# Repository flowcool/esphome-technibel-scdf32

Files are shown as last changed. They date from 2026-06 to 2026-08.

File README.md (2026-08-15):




[]()

**[🇬🇧 English](#-english)** · **[🇫🇷 Français](#-français)**

---

# ESPHome — Technibel SCDF32C5I IR Climate

> Fully reverse-engineered IR protocol + complete ESPHome / Home Assistant integration.  
> Protocole IR entièrement décodé + intégration ESPHome / Home Assistant complète.

---

## 🇬🇧 English

### What this is

This repository provides everything needed to control a **Technibel SCDF32C5I**
split air conditioner from Home Assistant using an ESP32 as an IR blaster.

The IR protocol was fully reverse-engineered from raw captures — Technibel uses a
**proprietary 48-bit protocol** that is not recognized by IRremoteESP8266. The frame
structure, encoding, and checksum formula are documented in [`docs/protocol.md`](docs/protocol.md).

**What you get:**
- `technibel_ir.h` — C++ IR frame builder (48-bit, checksum included)
- `ir-technibel-clim.yaml` — ESPHome transmitter config exposing a `send_command` service
- `ir-clim-sniffer.yaml` — ESPHome receiver config for capturing raw IR frames (debug use)
- `climate-technibel-ha.yaml` — Home Assistant MQTT climate entity (full package)

### Hardware (BOM)

See [`docs/bom.md`](docs/bom.md) for the full bill of materials.

| Component | Reference | Notes |
|---|---|---|
| MCU | ESP32 DevKit 30-pin | Any ESP32 board works |
| IR emitter | Diymore PCB0100 (2-channel) | Transistor + resistors built-in |
| IR receiver | KY-022 / VS1838B 38kHz | Sniffer phase only, not needed in final build |
| Capacitor | 100µF 16V electrolytic | Power filtering near TX module |

### Wiring

See [`docs/wiring.md`](docs/wiring.md) for the full ASCII diagram.

```
ESP32 GPIO4  ──► Diymore PCB0100 IN1   (IR transmitter)
ESP32 GPIO23 ◄── KY-022 OUT            (IR receiver — sniffer only)
```

### Installation

1. Copy `esphome/libraries/technibel_ir.h` to your ESPHome `config/libraries/` directory.
2. Flash `esphome/ir-technibel-clim.yaml` to your ESP32.
3. Add your `wifi_ssid`, `wifi_password`, and `ota_password` to your `secrets.yaml`.
4. In Home Assistant, add `homeassistant/climate-technibel-ha.yaml` to your packages directory.
5. Restart Home Assistant. The `climate.clim_sejour` entity will appear.

> **Note:** Adjust `sensor.thermometre_espace_de_vie_temperature` in `climate-technibel-ha.yaml`
> to match your own ambient temperature sensor entity ID.

### Usage in Home Assistant

Once installed, `climate.clim_sejour` supports:

| Feature | Values |
|---|---|
| HVAC modes | `off`, `cool`, `dry`, `fan_only`, `auto` |
| Fan modes | `auto`, `1`, `2`, `3`, `4`, `5`, `6` |
| Temperature range | 16°C – 30°C (1°C step) |
| Current temperature | From your HA temperature sensor |

Every state change (mode, temperature, fan speed) automatically sends the full IR
command to the AC via the ESP32.

### Protocol regression check

Run the dependency-free protocol verifier after changing captures, documentation,
or frame-generation code. It does not compile ESPHome or contact live devices:

```bash
python3 tests/verify_protocol.py
```

### Protocol overview

The Technibel SCDF32C5I uses a proprietary 48-bit IR protocol at 38kHz.
Frame: `B0 B1 B2 B3 B4 B5` (6 bytes). Checksum includes ambient temperature.

→ Full details in [`docs/protocol.md`](docs/protocol.md)

---

## 🇫🇷 Français

### Description

Ce dépôt contient tout le nécessaire pour piloter un climatiseur **Technibel SCDF32C5I**
depuis Home Assistant via un ESP32 émetteur IR.

Le protocole IR a été entièrement décodé par reverse engineering — Technibel utilise un
**protocole propriétaire 48 bits** non reconnu par IRremoteESP8266. C'est probablement
la première documentation publique de ce protocole.

**Contenu :**
- `technibel_ir.h` — constructeur de trames IR en C++ (48 bits, checksum inclus)
- `ir-technibel-clim.yaml` — config ESPHome émetteur, expose un service `send_command`
- `ir-clim-sniffer.yaml` — config ESPHome récepteur pour capture de trames brutes (debug)
- `climate-technibel-ha.yaml` — entité climate MQTT pour Home Assistant (package complet)

### Matériel (BOM)

Voir [`docs/bom.md`](docs/bom.md) pour la liste complète.

| Composant | Référence | Notes |
|---|---|---|
| MCU | ESP32 DevKit 30 broches | N'importe quel ESP32 fonctionne |
| Émetteur IR | Diymore PCB0100 (2 canaux) | Transistor + résistances intégrés |
| Récepteur IR | KY-022 / VS1838B 38kHz | Phase sniffer uniquement, inutile en prod |
| Condensateur | 100µF 16V électrolytique | Filtrage alim près du module TX |

### Câblage

Voir [`docs/wiring.md`](docs/wiring.md) pour le schéma ASCII complet.

```
ESP32 GPIO4  ──► Diymore PCB0100 IN1   (émetteur IR)
ESP32 GPIO23 ◄── KY-022 OUT            (récepteur IR — sniffer uniquement)
```

### Installation

1. Copier `esphome/libraries/technibel_ir.h` dans le dossier `config/libraries/` de votre ESPHome.
2. Flasher `esphome/ir-technibel-clim.yaml` sur votre ESP32.
3. Ajouter vos `wifi_ssid`, `wifi_password` et `ota_password` dans `secrets.yaml`.
4. Dans Home Assistant, ajouter `homeassistant/climate-technibel-ha.yaml` dans votre dossier `packages/`.
5. Redémarrer Home Assistant. L'entité `climate.clim_sejour` apparaît.

> **Note :** Remplacer `sensor.thermometre_espace_de_vie_temperature` dans `climate-technibel-ha.yaml`
> par l'entity_id de votre propre capteur de température ambiante.

### Utilisation dans Home Assistant

L'entité `climate.clim_sejour` une fois installée supporte :

| Fonction | Valeurs |
|---|---|
| Modes HVAC | `off`, `cool`, `dry`, `fan_only`, `auto` |
| Vitesses ventilateur | `auto`, `1`, `2`, `3`, `4`, `5`, `6` |
| Plage température | 16°C – 30°C (pas 1°C) |
| Température courante | Depuis votre capteur HA |

### Vérification de non-régression du protocole

Après toute modification des captures, de la documentation ou du générateur de
trames, lancer le vérificateur sans dépendance. Il ne compile pas ESPHome et ne
contacte aucun appareil :

```bash
python3 tests/verify_protocol.py
```

### Aperçu du protocole

Le Technibel SCDF32C5I utilise un protocole IR propriétaire 48 bits à 38kHz.
Trame : `B0 B1 B2 B3 B4 B5` (6 octets). Le checksum intègre la température ambiante.

→ Documentation complète dans [`docs/protocol.md`](docs/protocol.md)

---

## Protocol summary / Résumé protocole

| Byte | Value | Description |
|---|---|---|
| B0 | `0xD0` | Device address (fixed / fixe) |
| B1 | ambient+mode | High nibble = ambient temperature, low nibble: COOL=`0xC`, DRY=`0xA`, FAN=`0x9`, AUTO=`0xD` |
| B2 | temp+fan | hi nibble = temp encoded, lo nibble = fan speed |
| B3 | `0x18`/`0x08` | Power ON / OFF |
| B4 | `0x03` | Fixed / Fixe |
| B5 | checksum | Includes ambient temperature / Intègre T° ambiante |

→ [`docs/protocol.md`](docs/protocol.md) for full encoding tables and checksum formula.

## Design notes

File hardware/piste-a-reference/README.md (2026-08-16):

# Piste A reference perfboard

This directory is the construction authority for the fresh Phase 10 reference
board. The previous hand-drawn/SVG layout is obsolete and must not be used.

## Orientation and coordinates

- Board: isolated-pad FR4 perfboard, 30 × 70 mm, 10 columns × 24 rows.
- Component-side coordinates: columns `A`–`J` left to right, rows `1`–`24`
  top to bottom.
- The XIAO USB-C connector faces row 1.
- The solder-side PDF is already mirrored to match the board as held with the
  solder side facing the operator. Do not mirror it again.

## XIAO ESP32-C3 pin mapping

The schematic and PCB both represent the complete 2×7 XIAO socket:

| Left row, top to bottom | Function | Right row, top to bottom | Function |
|---:|---|---:|---|
| 1 | D0 | 8 | 5V / VBUS |
| 2 | D1 / GPIO3 | 9 | GND |
| 3 | D2 | 10 | 3V3 |
| 4 | D3 | 14 | D10 |
| 5 | D4 | 13 | D9 |
| 6 | D5 | 12 | D8 |
| 7 | D6 | 11 | D7 |

Only pins 2, 8, 9, and 10 are electrically used by this board. All other XIAO
pins remain available and unconnected.

## Mandatory polarity and pinout

- `Q1` is the Mouser onsemi `BC33740BU`. With the flat face toward the observer
  and leads down: pin 1 = Collector, pin 2 = Base, pin 3 = Emitter (`C-B-E`).
- `D1` must be a fresh Mouser Vishay `TSAL6400`: pin 2/anode/long lead at `F23`;
  pin 1/cathode/short lead/flat side at `G23`.
- `C3`: positive pin 1 at `J19`; negative pin 2/stripe at `I19`.
- `C2` and `C3` are directly across 5V and GND, before `R3`.

## Construction hold point

Before soldering, review these native and textual artifacts together:

1. `piste-a-reference.kicad_sch`
2. `piste-a-reference.kicad_pcb`
3. `wiring-table.md`

The current partially assembled board remains untouched as rollback/evidence.
Construction uses a new perfboard and fresh driver components.

## Verification

Install KiCad 9+ and run:

```bash
./verify-design.sh
```

The gate passes only when ERC reports zero errors/warnings and DRC reports zero
violations, zero unconnected pads, and zero schematic-parity problems.

The generator additionally requires `kicad-sch-api==0.5.6`:

```bash
python3 -m venv /tmp/piste-a-kicad-venv
/tmp/piste-a-kicad-venv/bin/pip install -r requirements.txt
/tmp/piste-a-kicad-venv/bin/python generate_design.py
```

Regeneration is deterministic for component placement, net assignments, and
wire coordinates. KiCad-generated UUIDs in the schematic may differ after a
full regeneration.

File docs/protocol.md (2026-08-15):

# Technibel SCDF32C5I — IR Protocol Documentation

**[🇬🇧 English](#-english)** · **[🇫🇷 Français](#-français)**

---

## 🇬🇧 English

### Overview

The Technibel SCDF32C5I uses a **proprietary 48-bit IR protocol** at 38kHz carrier frequency.
It is **not recognized** by IRremoteESP8266 (reported as UNKNOWN). Frames are static and
replayable — no rolling code.

| Parameter | Value |
|---|---|
| Carrier frequency | 38kHz |
| Frame length | 48 bits (6 bytes) |
| Header pulse | 6500µs |
| Header space | 3300µs |
| Bit pulse | ~450µs |
| Bit 1 space | ~2200µs |
| Bit 0 space | ~900µs |
| Bit order | MSB first per byte |

### Frame Structure

```
[ HEADER ] [ B0 ] [ B1 ] [ B2 ] [ B3 ] [ B4 ] [ B5 ] [ final pulse ]
```

| Byte | Example | Description |
|---|---|---|
| B0 | `0xD0` | Device address — always fixed |
| B1 | `0xAC` | Ambient temperature high nibble + operating mode nibble |
| B2 | `0x28` | Temperature (hi nibble) + fan speed (lo nibble) |
| B3 | `0x18` | Power ON flag (`0x08` = OFF) |
| B4 | `0x03` | Fixed — always `0x03` |
| B5 | checksum | Computed from B1, B2, and B3 |

### Mode encoding (B1 low nibble)

| Mode | Low nibble |
|---|---|
| COOL | `0xC` |
| DRY | `0xA` |
| FAN only | `0x9` |
| AUTO | `0xD` |

The high nibble of B1 carries the ambient temperature using the same encoding
as B2: `(reverseBits8(T_ambient - 4) >> 4) & 0xF`. For example, ambient 25°C
with COOL gives `B1=0xAC`, ambient 26°C gives `B1=0x6C`, and ambient 27°C
gives `B1=0xEC`.

> OFF is not a mode value — it is encoded in B3 (see Power flag below).

### Temperature encoding (B2 hi nibble)

Formula: `temp_hi = (reverseBits8(consigne - 4) >> 4) & 0xF`

| Temp | B2 hi nibble (hex) | Verified |
|---|---|---|
| 16°C | `0x90` | generated |
| 17°C | `0x10` | generated |
| 18°C | `0x70` | ✅ captured |
| 19°C | `0xF0` | ✅ captured |
| 20°C | `0x08` | ✅ captured |
| 21°C | `0x88` | generated* |
| 22°C | `0x48` | ✅ captured |
| 23°C | `0xC8` | ✅ captured |
| 24°C | `0x28` | ✅ captured |
| 25°C | `0xA8` | ✅ captured |
| 26°C | `0x68` | ✅ captured |
| 27°C | `0xE8` | generated |
| 28°C | `0x18` | generated |
| 29°C | `0x98` | generated |
| 30°C | `0x58` | generated |

*21°C capture was corrupted (AC displayed 24°C at capture time) — value generated from formula.

### Fan speed encoding (B2 lo nibble)

| Remote level | lo nibble | Captured frame (FAN, 23°C, ambient 24°C) |
|---|---|---|
| AUTO | `0x8` | `D0 29 C8 18 03 51` |
| FAN 1 / LOW | `0xC` | `D0 29 CC 18 03 55` |
| FAN 2 | `0xA` | `D0 29 CA 18 03 53` |
| FAN 3 / MED | `0xE` | `D0 29 CE 18 03 57` |
| FAN 4 | `0x9` | `D0 29 C9 18 03 50` |
| FAN 5 | `0xD` | `D0 29 CD 18 03 54` |
| FAN 6 / HIGH | `0xB` | `D0 29 CB 18 03 52` |

All seven values were captured in one controlled campaign on 2026-08-15. The
complete raw timings are preserved in `captures/fan-campaign-2026-08-15.jsonl`.

### B2 full formula

```
B2 = (temp_hi_nibble << 4) | fan_lo_nibble
```

Example: COOL, 24°C, AUTO fan → `B2 = (0x2 << 4) | 0x8 = 0x28`

### Power / change flag (B3)

| Value | Meaning |
|---|---|
| `0x18` | Power ON (or command update while running) |
| `0x08` | Power OFF |

> Always use `0x18` when sending a command from Home Assistant, even just to change
> the setpoint — the AC needs this flag to apply the new value.

### Checksum (B5)

```
B5 = reverseBits8(
       (reverseBits8(B1) + reverseBits8(B2) + reverseBits8(B3) + 0xCB) & 0xFF
     )
```

The ambient temperature is included indirectly through the high nibble of B1,
and the operating mode through its low nibble. The former formula using
`T_ambient - 25` was a COOL-only reduction: for COOL, B1's low nibble is fixed
to `0xC`, so `reverseBits8(B1) + 0xCB` reduces to `T_ambient - 25` modulo 256.
It must not be used for DRY, FAN, or AUTO frames.

### OFF frame (fixed)

```
D0 AC A8 08 03 A4
```

This frame was pre-computed with B3=`0x08` (power off) and ambient=25°C.
It reliably turns off the AC regardless of the previous mode or setpoint.

### Reverse engineering notes

- Captured using ESP32 + KY-022 TSOP IR receiver + ESPHome `remote_receiver` (`dump: all`)
- Decoded from Pronto hex format dumped in ESPHome logs
- Protocol confirmed **NOT rolling-code** — static frames, fully replayable
- IRremoteESP8266 does not recognize this protocol (reported as UNKNOWN)
- The `reverseBits8` function is central to both temperature encoding and checksum

---

## 🇫🇷 Français

### Vue d'ensemble

Le Technibel SCDF32C5I utilise un **protocole IR propriétaire 48 bits** à 38kHz.
Il n'est **pas reconnu** par IRremoteESP8266 (renvoyé comme UNKNOWN). Les trames sont
statiques et rejouables — pas de code tournant.

| Paramètre | Valeur |
|---|---|
| Fréquence porteuse | 38kHz |
| Longueur de trame | 48 bits (6 octets) |
| Header pulse | 6500µs |
| Header space | 3300µs |
| Pulse par bit | ~450µs |
| Space bit 1 | ~2200µs |
| Space bit 0 | ~900µs |
| Ordre des bits | MSB en premier par octet |

### Structure de trame

```
[ HEADER ] [ B0 ] [ B1 ] [ B2 ] [ B3 ] [ B4 ] [ B5 ] [ pulse final ]
```

| Octet | Exemple | Description |
|---|---|---|
| B0 | `0xD0` | Adresse device — toujours fixe |
| B1 | `0xAC` | Nibble haut température ambiante + nibble bas mode |
| B2 | `0x28` | Température (nibble hi) + vitesse ventilo (nibble lo) |
| B3 | `0x18` | Flag marche (`0x08` = arrêt) |
| B4 | `0x03` | Fixe — toujours `0x03` |
| B5 | checksum | Calculé depuis B1, B2 et B3 |

### Encodage des modes (nibble bas de B1)

| Mode | Nibble bas |
|---|---|
| COOL | `0xC` |
| DRY (déshumidification) | `0xA` |
| FAN only (ventilation) | `0x9` |
| AUTO | `0xD` |

Le nibble haut de B1 encode la température ambiante avec la même formule que
B2 : `(inverseBits8(T_ambiant - 4) >> 4) & 0xF`. Ainsi, à 25°C en COOL,
`B1=0xAC`, à 26°C `B1=0x6C`, et à 27°C `B1=0xEC`.

> OFF n'est pas une valeur de mode — il est encodé dans B3 (voir Flag d'alimentation).

### Encodage température (nibble hi de B2)

Formule : `temp_hi = (inverseBits8(consigne - 4) >> 4) & 0xF`

Voir tableau complet en section anglaise — valeurs identiques.

### Encodage vitesse ventilateur (nibble lo de B2)

| Niveau télécommande | nibble lo | Trame capturée (FAN, 23°C, ambiante 24°C) |
|---|---|---|
| AUTO | `0x8` | `D0 29 C8 18 03 51` |
| FAN 1 / LOW | `0xC` | `D0 29 CC 18 03 55` |
| FAN 2 | `0xA` | `D0 29 CA 18 03 53` |
| FAN 3 / MED | `0xE` | `D0 29 CE 18 03 57` |
| FAN 4 | `0x9` | `D0 29 C9 18 03 50` |
| FAN 5 | `0xD` | `D0 29 CD 18 03 54` |
| FAN 6 / HIGH | `0xB` | `D0 29 CB 18 03 52` |

Les sept valeurs ont été capturées pendant une campagne contrôlée le 2026-08-15.
Les timings bruts complets sont conservés dans
`captures/fan-campaign-2026-08-15.jsonl`.

### Formule complète de B2

```
B2 = (nibble_hi_temp << 4) | nibble_lo_ventilo
```

### Flag alimentation (B3)

| Valeur | Signification |
|---|---|
| `0x18` | Allumage (ou mise à jour de consigne) |
| `0x08` | Extinction |

> Toujours utiliser `0x18` depuis Home Assistant, même pour changer uniquement
> la consigne — le climatiseur nécessite ce flag pour appliquer la nouvelle valeur.

### Checksum (B5)

```
B5 = inverseBits8(
       (inverseBits8(B1) + inverseBits8(B2) + inverseBits8(B3) + 0xCB) & 0xFF
     )
```

La température ambiante est incluse indirectement par le nibble haut de B1, et
le mode par son nibble bas. L'ancienne formule utilisant `T_ambiant - 25` était
une réduction valable uniquement en mode COOL : le nibble bas de B1 y vaut
toujours `0xC`, donc `inverseBits8(B1) + 0xCB` se réduit à `T_ambiant - 25`
modulo 256. Elle ne doit pas être utilisée pour les modes DRY, FAN ou AUTO.

### Trame OFF (fixe)

```
D0 AC A8 08 03 A4
```

Pré-calculée avec B3=`0x08` (extinction) et ambiant=25°C. Éteint le climatiseur
de manière fiable quel que soit le mode ou la consigne précédents.

### Notes de reverse engineering

- Capture réalisée avec ESP32 + récepteur KY-022 TSOP + ESPHome `remote_receiver` (`dump: all`)
- Décodage depuis le format Pronto hex dans les logs ESPHome
- Protocole confirmé **sans code tournant** — trames statiques, rejouables
- IRremoteESP8266 ne reconnaît pas ce protocole (rapporté comme UNKNOWN)
- La fonction `inverseBits8` est centrale dans l'encodage température et le checksum

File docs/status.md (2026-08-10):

# État des lieux historique & TODO (2026-07-04)

> Note : ce document est un suivi de session de debug, en français uniquement
> (contrairement aux autres docs du repo qui sont bilingues). À nettoyer/fusionner
> dans `troubleshooting.md` une fois le problème matériel résolu.
>
> Mise à jour d'architecture (2026-08-10) : les mentions NAS et chemins
> `/volume1/...` ci-dessous décrivent uniquement l'ancien environnement. Le live
> ESPHome/Home Assistant est désormais sur une VM dédiée. Ses chemins et son mode
> de déploiement doivent être vérifiés avant toute action.

## Ce qui fonctionne (validé de bout en bout)

La chaîne logicielle complète a été testée avec succès :

```
Carte Mushroom (climate.clim_sejour)
  → entité MQTT climate (packages/clim_sejour.yaml)
  → automatisation "Clim Séjour — Envoyer commande IR"
  → service esphome.ir_technibel_clim_send_command
  → firmware ir-technibel-clim.yaml (lambda + technibel_ir.h)
  → remote_transmitter → GPIO4
```

Log de confirmation obtenu (via logs série USB) :
```
[technibel] IR sent: mode=COOL temp=21 fan=LOW amb=24 power=ON
```

Le calcul de trame (`technibel_ir.h`) a été vérifié manuellement contre l'exemple
documenté dans `protocol.md` (trame OFF `D0 AC 28 08 43 64`) — checksum et
encodage température corrects.

## Bugs logiciels trouvés et corrigés pendant cette session

1. **IP obsolète en cache côté HA** — l'intégration ESPHome pour `ir-technibel-clim`
   gardait `host: 192.168.2.156` alors que l'ESP32 (pas d'IP statique, DHCP) avait
   changé d'adresse. Résultat : `Errno 113 (No route to host)` en boucle dans
   `home-assistant.log`, aucun appel de service n'atteignait jamais l'ESP32.
2. **Automatisation désactivée** — "Clim Séjour — Envoyer commande IR" était
   basculée off dans l'UI HA, indépendamment du problème réseau ci-dessus. Son
   état (on/off) est stocké dans le registre HA (`.storage`), pas dans le YAML —
   donc un simple redémarrage HA ne la réactive pas automatiquement.

## Tentative de refonte annulée

Essai de remplacer MQTT + automatisation par un `climate: platform: template`
natif ESPHome (pour supprimer un point de défaillance). **Ce composant n'existe
pas** dans ESPHome — vérifié directement dans le conteneur : le composant
`template` ne fournit pas de plateforme `climate` (seulement sensor, switch,
fan, cover, number, etc.). Erreur : `Platform not found: 'climate.template'`.

Tout a été annulé et restauré à l'identique :
- `esphome/ir-technibel-clim.yaml` (repo + NAS)
- `homeassistant/climate-technibel-ha.yaml` (repo)
- `packages/clim_sejour.yaml` (NAS)

Le firmware sur l'ESP32 n'a **jamais été reflashé** avec la version cassée
(la compilation a échoué avant tout flash) — le device tourne toujours la
version fonctionnelle testée plus haut.

**Si on veut retenter un jour** : la seule vraie voie native pour un protocole
IR custom est un composant `climate_ir` (vraie classe C++ héritant de
`climate_ir::ClimateIR`, structure `external_component` complète) — plus
lourd qu'un simple template YAML. Toujours valider avec `esphome config`
avant de dire que c'est prêt.

## Découverte annexe historique : repo git ≠ ancien dossier live NAS

`~/claude_project/esphome-technibel-scdf32` (ce repo) et
`/volume1/docker/homeassistant/esphome/` (dossier monté dans le conteneur
ESPHome, ce que voit réellement le dashboard) sont **deux copies séparées**.
Avant cette session, `ir-technibel-clim.yaml` n'existait que dans le repo,
pas côté NAS (seule `libraries/technibel_ir.h` avait été copiée). À garder
en tête : toute modif du repo doit être copiée manuellement vers le NAS pour
être prise en compte par le dashboard.

## Problème matériel non résolu : pas de bip de la clim

Point bloquant actuel. Une fois le logiciel confirmé fonctionnel (log "IR
sent"), l'ESP32 remis en position devant la climatisation **ne déclenche
aucun bip**. Ce qui a été vérifié bon pendant cette session :

- LED TSAL6400 : tension directe ~1.3V cohérente (diode test)
- Transistor 2N2222 : bon hors circuit (Base-Emitter ~650mV, Base-Collector
  ~650mV, Collector-Emitter OL)
- Continuité câblage 3V3 → R22Ω → anode → cathode → collector : bonne (après
  avoir retrouvé et réparé un lien Collector↔Cathode décroché)
- Alimentation 3V3 : ~3V confirmé

Ce qui reste non concluant :
- Tension du collecteur au repos incohérente selon le calibre du multimètre
  (0V/OL sur calibre 4V, 6V sur calibre 40V) — probablement une limite du
  multimètre sur ce nœud, jamais totalement élucidé
- Pas de test caméra possible (le téléphone ne voit même pas une télécommande
  TV classique — caméra inutilisable pour ce diagnostic)
- Câblage jamais re-vérifié après le dernier déplacement physique du montage
  devant la clim — `wiring.md` signale explicitement la fragilité des fils
  Dupont sur pattes nues en cas de manipulation

## TODO pour repartir propre

1. Redémarrer HA pour recharger `packages/clim_sejour.yaml` (restauré)
2. Vérifier/réactiver manuellement l'automatisation dans l'UI HA après le
   redémarrage (Paramètres → Automatisations)
3. Retester une commande réelle pour confirmer le retour à l'état
   fonctionnel d'avant l'incident
4. Refaire la continuité **après le dernier déplacement du montage** :
   - Collector (droite) ↔ Cathode LED
   - Emitter (gauche) ↔ GND
   - Base (milieu) ↔ sortie résistance 470Ω
5. Vérifier l'orientation de la LED et son alignement/distance par rapport
   à la fenêtre réceptrice IR de la climatisation
6. Envisager une IP statique (`wifi: manual_ip:`) dans
   `ir-technibel-clim.yaml` pour éviter de reperdre la connexion HA au
   prochain reboot/reflash
7. Se souvenir de copier tout futur changement du repo vers le dossier live
   NAS (`/volume1/docker/homeassistant/esphome/`) — les deux ne se
   synchronisent pas automatiquement

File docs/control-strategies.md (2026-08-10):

# Stratégies de pilotage / Control Strategies

**[🇫🇷 Français](#-français)** · **[🇬🇧 English](#-english)**

---

## 🇫🇷 Français

Ce document compare les différentes approches pour piloter la clim Technibel depuis Home Assistant,
du plus simple au plus invasif.

---

### ⚡ Prérequis — Alimentation de l'ESP32

**C'est le point d'entrée de tout.** Avant de choisir une piste, il faut savoir d'où vient le jus.

L'unité intérieure a toujours une alimentation interne pour son propre MCU et récepteur IR :

```
220V ──► SMPS interne ──► 12V  (moteur ventilateur)
                      └──► 5V ou 3.3V  (logique MCU, TSOP, afficheur)
```

**À faire à la première ouverture de la clim :**
1. Couper au disjoncteur, attendre 5 min (condensateurs)
2. Ouvrir le capot
3. Vérifier l'isolation secteur/logique (voir plan phase 12)
4. Mesurer les tensions disponibles sur le PCB (chercher les rails d'alimentation, souvent marqués +5V, +12V, GND)
5. Évaluer la capacité du rail (≥500mA de marge pour un XIAO avec WiFi)

| Rail trouvé | Solution alimentation ESP32 |
|---|---|
| 5V interne, capacité suffisante | Brancher sur la broche 5V du XIAO via diode Schottky (SS14, anode côté rail, cathode côté XIAO — recommandation Seeed pour alimentation externe par broche 5V). **Ne JAMAIS brancher 5V sur la broche 3V3** — cela détruit le régulateur. |
| 12V uniquement | Ajouter un module buck 12V→5V (~1€, taille timbre-poste) → broche 5V via diode |
| Rien d'accessible | Revenir à la Piste A (prise externe) |

**Si l'alim interne est exploitable → installation 100% intégrée :**
- Zéro multiprise
- Zéro câble visible
- L'ESP32 vit dans la clim et s'alimente depuis la clim

---

### Piste A — ESP32 monté derrière/sous la clim

**Principe :** installer une double prise derrière l'unité intérieure, y brancher un adaptateur USB,
et coller la LED IR directement sous le récepteur de la clim.

**Avantages :**
- Distance LED → récepteur : ~5 cm → aucun problème de puissance ni d'angle
- N'importe quelle LED 940nm 5mm suffit (y compris la TSAL6400 actuelle)
- Non invasif, entièrement réversible
- Câblage identique au schéma principal (`docs/wiring.md`)

**Matériel supplémentaire :**
- 1 double prise électrique (faible courant USB suffit — 500 mA)
- 1 adaptateur secteur → USB 5V
- Éventuellement un peu de velcro ou de double face pour fixer l'ESP32

**Points d'attention :**
- Vérifier que la prise peut être installée derrière la clim sans gêner la fixation murale
- Laisser un accès pour éventuellement reflasher l'ESP32 via USB

---

### Piste B1 — Injection directe sur le récepteur IR interne

**Principe :** à l'intérieur de l'unité intérieure se trouve un récepteur IR (composant TSOP,
3 broches : VCC, GND, Signal). On branche l'ESP32 directement sur la broche Signal et on
envoie les trames électriquement, sans émission IR physique.

```
TSOP interne
┌──────────────────────────────┐
│  photodiode → filtre 38kHz   │
│  → démodulateur → sortie     │
└──────────────────────────────┘
  VCC     GND     Signal (OUT)
                      ↑
               brancher ici
```

> **Note :** Le TSOP n'a pas de broche "entrée" électrique accessible — la photodiode est
> à l'intérieur du boîtier. Le seul point d'injection électrique réaliste est la broche
> Signal (sortie), côté MCU de la clim.

**Avantages :**
- Zéro contrainte optique (angle, distance, faisceau)
- Télécommande d'origine **préservée** — le TSOP reste actif et reçoit toujours l'IR
- Signal électrique direct = fiabilité maximale
- Réversible : débrancher 3 fils suffit à revenir à l'état d'origine

**Protection de l'ESP32 et translation de niveau :**

⚠️ Les GPIO de l'ESP32-C3 ne sont **PAS tolérants 5V** (max 3.6V, datasheet Espressif).
Le GPIO ne doit JAMAIS être directement connecté à une ligne pouvant atteindre 5V,
même en mode open_drain (open_drain empêche de sourcer, mais n'empêche pas de recevoir
du 5V via les diodes ESD internes → dommage au chip).

**Circuit conditionnel : BC337 comme sortie open-collector de translation de niveau.**

Ce branchement direct en parallèle est permis uniquement si la sortie du récepteur IR
est confirmée open-collector/open-drain et si la logique de la clim est confirmée comme
une basse tension isolée du secteur. Le BC337 ne fournit aucune isolation galvanique.

```
ESP32 GPIO ──[470Ω]──┬── Base BC337
                      │
                    [10kΩ] ← pull-down (OFF au boot)
                      │
GND ─────────────────┴── Emitter BC337

Ligne Signal vers MCU clim ── Collector BC337
```

Le BC337 agit comme une sortie open-collector externe :
- GPIO HIGH → BC337 conducteur → ligne tirée LOW (mark)
- GPIO LOW → BC337 coupé → ligne flottante, tirée HIGH par le circuit existant
- Aucune tension de la clim n'arrive sur le GPIO ESP32
- Le collecteur accepte une ligne tirée à 3.3V ou 5V, dans les limites du BC337

**Coexistence avec la télécommande :** dépend du type de sortie du TSOP.
- TSOP open-collector : pas de modification. Les deux sinkent sur la même ligne.
- TSOP push-pull : ne pas connecter directement le collecteur. Couper la piste TSOP→MCU et recombiner
  via wired-OR (deux diodes + pull-up). Le circuit exact dépend du PCB — à décider
  après mesures (voir plan de validation, phases 13-14).

**Étapes câblage :**
1. Vérifier l'isolation électrique de la logique clim (voir plan, phase 12)
2. Ouvrir le capot de l'unité intérieure (vis cachées sous les grilles ou caches)
3. Localiser le module récepteur IR (petit composant noir 3 broches)
4. Identifier les 3 broches : VCC, GND, Signal (datasheet du composant identifié)
5. Mesurer la tension VCC du récepteur (3.3V ou 5V)
6. Relever avec l'analyseur logique uniquement la polarité et le timing ; mesurer VCC et
   le niveau HIGH avec un instrument adapté, puis déterminer OC/PP depuis la référence
   exacte du récepteur et l'inspection du PCB (voir phases 12-13)
7. Seulement si la sortie est confirmée open-collector : brancher le collecteur du BC337 sur la ligne Signal
8. Brancher les GND ensemble
9. **Ne pas alimenter le TSOP depuis l'ESP32** — le laisser alimenté par le board clim

**Modification firmware :**

Changer uniquement la config `remote_transmitter` dans le YAML — `technibel_ir.h` ne change pas :

```yaml
remote_transmitter:
  pin:
    number: GPIO3
    inverted: false       # le BC337 ajoute une inversion logique :
                          # GPIO HIGH → transistor ON → ligne LOW (mark)
                          # à déterminer expérimentalement — essayer false puis true
  carrier_duty_percent: 100   # signal DC, pas de porteuse 38kHz
  non_blocking: false
  rmt_symbols: 96
```

`carrier_duty_percent: 100` est un usage officiel ESPHome, documenté pour les émetteurs RF
433MHz — même principe : timings bruts sans porteuse sur GPIO direct.

**Points d'attention :**
- Couper l'alimentation de la clim au disjoncteur avant toute intervention
- Ne pas toucher aux condensateurs ni aux circuits haute tension
- **Ne PAS supposer que la logique de l'unité intérieure est isolée du secteur** — certaines
  alimentations d'électroménager référencent la masse logique au secteur. Vérifier l'isolation
  avant de connecter tout instrument USB (analyseur logique, oscilloscope) — voir plan phase 12
- Faire une photo du câblage original avant de toucher quoi que ce soit

---

### Piste B2 — Interception du bus interne PCB

**Principe :** identifier le protocole de communication entre le récepteur IR et le
microcontrôleur principal de la clim (souvent UART, I²C ou un bus propriétaire),
puis s'y intercaler pour envoyer des commandes directement au MCU.

**Avantages :**
- Contournement total du récepteur IR
- Contrôle potentiellement plus riche (lecture d'état, températures internes, etc.)

**Inconvénients :**
- Nécessite du reverse engineering sur le PCB (oscilloscope recommandé)
- Protocole potentiellement propriétaire et non documenté
- Risque de brick du board clim si mauvaise manipulation
- Beaucoup plus long à mettre en œuvre

**Quand l'envisager :** uniquement si la Piste B1 échoue ou si on veut lire des données
internes (température du serpentin, état du compresseur, etc.) non disponibles via IR.

---

### Tableau récapitulatif

| Critère | Piste A | Piste B1 | Piste B2 |
|---|---|---|---|
| Difficulté | Facile | Moyenne | Avancée |
| Invasif | Non | Légèrement | Oui |
| Réversible | Oui | Oui | Partiellement |
| Fiabilité | Bonne | Excellente | Excellente |
| Temps d'installation | 30 min | 1–2h | Plusieurs jours |
| Risque matériel | Aucun | Faible | Modéré |

---

## 🇬🇧 English

This document compares the different approaches to control the Technibel AC unit from Home Assistant,
from simplest to most invasive.

---

### ⚡ Prerequisite — Powering the ESP32

**This is the entry point for everything.** Before choosing an option, find out where the power comes from.

The indoor unit always has an internal power supply for its own MCU and IR receiver:

```
220V ──► Internal SMPS ──► 12V  (fan motor)
                       └──► 5V or 3.3V  (MCU logic, TSOP, display)
```

**To do on first opening of the AC unit:**
1. Cut power at the breaker, wait 5 min (capacitors)
2. Open the cover
3. Verify mains/logic isolation (see validation plan phase 12)
4. Measure available voltages on the PCB (look for power rails, often labeled +5V, +12V, GND)
5. Evaluate rail capacity (≥500mA headroom needed for XIAO with WiFi)

| Rail found | ESP32 power solution |
|---|---|
| Internal 5V, sufficient capacity | Connect to XIAO 5V pin via Schottky diode (SS14, anode toward rail, cathode toward XIAO — per Seeed recommendation for external power via 5V pin). **NEVER connect 5V to the 3V3 pin** — this destroys the regulator. |
| 12V only | Add a 12V→5V buck module (~€1, stamp-sized) → 5V pin via diode |
| Nothing accessible | Fall back to Option A (external outlet) |

**If the internal supply works → 100% integrated install:**
- No power strip
- No visible cables
- ESP32 lives inside the AC and feeds from the AC

---

### Option A — ESP32 mounted behind/under the AC unit

**Principle:** install a power outlet behind the indoor unit, plug in a USB adapter,
and stick the IR LED directly under the AC receiver window.

**Advantages:**
- LED to receiver distance: ~5 cm → no power or angle issues whatsoever
- Any 940nm 5mm LED works (including the current TSAL6400)
- Non-invasive, fully reversible
- Same wiring as the main schematic (`docs/wiring.md`)

**Additional hardware:**
- 1 electrical outlet (low current — 500 mA USB is enough)
- 1 mains → USB 5V adapter
- Some velcro or double-sided tape to mount the ESP32

**Watch out for:**
- Make sure the outlet can fit behind the AC without blocking the wall mount
- Leave USB access for reflashing the ESP32 if needed

---

### Option B1 — Direct injection into the internal IR receiver

**Principle:** inside the indoor unit there is an IR receiver (TSOP component, 3 pins: VCC, GND, Signal).
Connect the ESP32 directly to the Signal pin and send frames electrically, with no physical IR emission.

```
Internal TSOP
┌──────────────────────────────┐
│  photodiode → 38kHz filter   │
│  → demodulator → output      │
└──────────────────────────────┘
  VCC     GND     Signal (OUT)
                      ↑
               connect here
```

> **Note:** The TSOP has no accessible electrical "input" pin — the photodiode is inside the package.
> The only practical electrical injection point is the Signal (output) pin, on the AC MCU side.

**Advantages:**
- Zero optical constraints (angle, distance, beam)
- Original remote control **preserved** — TSOP stays active and still receives IR
- Direct electrical signal = maximum reliability
- Reversible: disconnect 3 wires to restore original state

**ESP32 protection and level shifting:**

⚠️ ESP32-C3 GPIOs are **NOT 5V-tolerant** (max 3.6V, Espressif datasheet).
The GPIO must NEVER be directly connected to a line that can reach 5V, even in
open_drain mode (open_drain prevents sourcing, but does not prevent receiving 5V
through internal ESD diodes → chip damage).

**Conditional circuit: BC337 as an open-collector level-shifting output.**

This direct parallel connection is allowed only when the IR receiver output is confirmed
open-collector/open-drain and the AC logic is confirmed to be isolated extra-low voltage.
The BC337 provides no galvanic isolation.

```
ESP32 GPIO ──[470Ω]──┬── Base BC337
                      │
                    [10kΩ] ← pull-down (OFF at boot)
                      │
GND ─────────────────┴── Emitter BC337

Signal line to AC MCU ── Collector BC337
```

The BC337 acts as an external open-collector output:
- GPIO HIGH → BC337 conducts → line pulled LOW (mark)
- GPIO LOW → BC337 off → line floats, pulled HIGH by existing circuit
- No voltage from the AC signal line ever reaches the ESP32 GPIO
- The collector supports a 3.3V or 5V pulled-up line within the BC337 ratings

**Remote coexistence:** depends on TSOP output type.
- TSOP open-collector: no modification needed. Both sink on the same line.
- TSOP push-pull: do not connect the collector directly. Cut the TSOP→MCU trace and recombine
  via wired-OR (two diodes + pull-up). Exact topology depends on PCB — decide
  after measurements (see validation plan, phases 13-14).

**Wiring steps:**
1. Verify electrical isolation of the AC logic board (see plan, phase 12)
2. Open the indoor unit cover (screws hidden under grilles or covers)
3. Locate the IR receiver module (small black 3-pin component)
4. Identify the 3 pins: VCC, GND, Signal (from identified component's datasheet)
5. Measure VCC voltage (3.3V or 5V)
6. Use the logic analyzer only for polarity and timing; measure VCC and the HIGH level
   with a suitable instrument, then determine OC/PP from the receiver's exact reference
   and PCB inspection (see phases 12-13)
7. Only for a confirmed open-collector output: connect the BC337 collector to the Signal line
8. Connect GNDs together
9. **Do not power the TSOP from the ESP32** — leave it powered by the AC board

**Firmware change:**

Only the `remote_transmitter` config changes — `technibel_ir.h` stays untouched:

```yaml
remote_transmitter:
  pin:
    number: GPIO3
    inverted: false       # BC337 adds a logic inversion:
                          # GPIO HIGH → transistor ON → line LOW (mark)
                          # determine experimentally — try false then true
  carrier_duty_percent: 100   # DC signal, no 38kHz carrier
  non_blocking: false
  rmt_symbols: 96
```

`carrier_duty_percent: 100` is an official ESPHome feature, documented for 433MHz RF transmitters —
same principle: raw timings on a GPIO with no carrier modulation.

**Watch out for:**
- Cut power to the AC unit at the breaker before any intervention
- Do not touch capacitors or high-voltage circuits
- **Do NOT assume the indoor unit's logic is isolated from mains** — some appliance PSUs
  reference logic ground to mains. Verify isolation before connecting any USB instrument
  (logic analyzer, oscilloscope) — see validation plan phase 12
- Photograph original wiring before touching anything

---

### Option B2 — Internal PCB bus interception

**Principle:** identify the communication protocol between the IR receiver and the AC's main
microcontroller (often UART, I²C, or a proprietary bus), then insert the ESP32 in-line
to send commands directly to the MCU.

**Advantages:**
- Completely bypasses the IR receiver
- Potentially richer control (state readback, internal temperatures, etc.)

**Disadvantages:**
- Requires PCB reverse engineering (oscilloscope recommended)
- Protocol may be proprietary and undocumented
- Risk of bricking the AC board if mishandled
- Much longer to implement

**When to consider:** only if Option B1 fails, or if you need to read internal data
(coil temperature, compressor state, etc.) not available via IR.

---

### Summary table

| Criteria | Option A | Option B1 | Option B2 |
|---|---|---|---|
| Difficulty | Easy | Medium | Advanced |
| Invasive | No | Slightly | Yes |
| Reversible | Yes | Yes | Partially |
| Reliability | Good | Excellent | Excellent |
| Install time | 30 min | 1–2h | Several days |
| Hardware risk | None | Low | Moderate |

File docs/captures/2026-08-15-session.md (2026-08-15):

# Technibel IR capture log — 2026-08-15

This is a chronological laboratory log for the ESPHome Technibel reverse-engineering work.
It deliberately keeps uncertain observations separate from decoded control frames.

## Recording rules

- Record local time (Europe/Zurich), source (`remote` or `xiao`), and the state shown on the remote before pressing a button.
- Keep every packet class: short Pronto packets, non-standard symbol counts, and the canonical `n_sym=99` frame.
- Preserve the raw Pronto line before decoding. A decoded six-byte frame is an interpretation, not a replacement for the raw capture.
- Mark the physical result separately: no response, beep, fan movement, LED change, or unknown.

## Chronology

| Time | Source/action | Displayed or requested state | Capture | Physical result | Interpretation |
|---|---|---|---|---|---|
| 14:21:24 | XIAO service | COOL, 24°C, AUTO, ambient 26°C, ON | `n_sym=99`; `D0 6C 28 18 03 B4` | One beep reported | Exact sender frame and optical path confirmed |
| 14:24:39 | Original remote | COOL, 23°C, AUTO, ambient 24°C | `n_sym=99` | Reference capture | Remote reference for exact-state replay |
| 14:25:14 | XIAO service | COOL, 23°C, AUTO, ambient 24°C, ON | `n_sym=99`; `D0 2C C8 18 03 54` | One beep reported | Exact-state replay accepted by IR receiver |
| 14:26:23 | XIAO service | OFF, 23°C, AUTO, ambient 24°C | `n_sym=99`; `D0 2C C8 08 03 74` | Unit reported stopped | OFF frame emitted and received optically |
| 14:33:31 | XIAO service | FAN, HIGH, 23°C, ambient 24°C, ON | `n_sym=99` | No beep, no fan | FAN semantics not validated |
| 14:34:51 | Original remote | FAN operation; exact prior fan state uncertain | `n_sym=104` | Reference capture | Non-standard lead/transition packet; raw line below |
| 14:34:53 | Original remote | FAN operation; exact prior fan state uncertain | `n_sym=99` | Reference capture | Standard follow-up frame; raw line below |
| 14:36:32 | Original remote | Operator later corrected this was FAN AUTO, not FAN HIGH | `n_sym=99` | Reference capture | Cannot infer transition semantics from this event |
| 14:38:36 | Original remote | Return toward AUTO; exact button sequence uncertain | short `000D` | Reference capture | Short transition/status packet |
| 14:38:38 | Original remote | Return toward AUTO; exact button sequence uncertain | `n_sym=82` | Reference capture | Non-standard transition packet |
| 14:38:47 | Original remote | Return toward AUTO; exact button sequence uncertain | `n_sym=99` | Reference capture | Standard follow-up frame |
| 14:41:53 | Original remote | FAN 1 (operator label; exact vendor speed name not yet mapped) | `n_sym=99` | Reference capture | First long frame after FAN 1 action |
| 14:42:03 | Original remote | FAN 1 | `n_sym=99` | Reference capture | Second long frame 10 s later; possible status/repeat |
| 14:42:47 | Original remote | FAN 2 | `n_sym=99` | Reference capture | First long frame after FAN 2 action |
| 14:42:49 | Original remote | FAN 2 | `n_sym=99` | Reference capture | Repeat 1.5 s later |
| 14:42:51 | Original remote | FAN 2 | `n_sym=99` | Reference capture | Repeat 2 s later |
| 14:42:56 | Original remote | FAN 2 | `n_sym=99` | Reference capture | Repeat 5 s later |
| 14:43:31 | Original remote | FAN 2 | `n_sym=99` | Reference capture | Later periodic/repeat frame |
| 14:43:38 | Original remote | FAN 2 | `n_sym=99` | Reference capture | Later periodic/repeat frame |
| 14:44:28 | Original remote | FAN 3 | `n_sym=99` | Reference capture | One long frame observed after FAN 3 action |
| 14:44:56 | Original remote | FAN 4 | `n_sym=99` | Reference capture | One long frame observed after FAN 4 action |
| 14:45:26 | Original remote | FAN 5 | `n_sym=99` | Reference capture | One long frame observed after FAN 5 action |
| 14:45:49 | Original remote | FAN 6 | `n_sym=99` | Reference capture | First long frame after FAN 6 action |
| 14:45:57 | Original remote | FAN 6 | `n_sym=99` | Reference capture | Second long frame 8 s later |
| 14:46:40 | Original remote | FAN mode, fan AUTO after FAN 6 maximum; ambient 25°C, setpoint 23°C | `n_sym=99`; prefix `D0 A9 C8` | Reference capture | Old inferred suffix `18 03 D4` used the COOL-only checksum reduction; general formula predicts `18 03 D1` |
| 14:55:09 | Original remote | FAN 1; ambient 25°C, setpoint 23°C | `n_sym=99`; candidate `D0 A9 CC 18 03 D5` | Reference capture | Candidate fan nibble `C`; checksum/raw timing needs cross-check |
| 14:57:12 | Original remote | FAN 2; ambient 25°C, setpoint 23°C | `n_sym=99`; candidate `D0 A9 CA 18 03 D3` | Reference capture | Candidate fan nibble `A`; checksum/raw timing needs cross-check |
| 14:57:39 | Original remote | FAN 3; ambient 25°C, setpoint 23°C | `n_sym=99`; `D0 A9 CE 0C 00 F5` | Reference capture | Ambiguous status/transition variant (`B3/B4=0C/00`); do not use for mapping yet |
| 14:58:10 | Original remote | FAN 4; ambient 25°C, setpoint 23°C | `n_sym=99`; candidate prefix `D0 A9 C9` | Reference capture | Candidate fan nibble `9`; full bytes/checksum pending cross-check |
| 14:58:55 | Original remote | FAN 5; ambient 25°C, setpoint 23°C | `n_sym=99` | Reference capture | Raw extraction does not produce a stable standard command prefix; classify as ambiguous/status pending repeat |
| 14:59:32 | Original remote | FAN 6; ambient 25°C, setpoint 23°C | `n_sym=99` | Reference capture | Raw extraction does not produce a stable standard command prefix; classify as ambiguous/status |
| 15:00:01 | Original remote | FAN mode, fan AUTO; ambient 25°C, setpoint 23°C | `n_sym=99`; prefix `D0 A9 C8` (corrected expected full `D0 A9 C8 18 03 D1`) | Reference capture | Confirms fan AUTO nibble `8` in the FAN context; suffix corrected by the general checksum formula |

## Raw captures retained in ESPHome logs

The complete raw Pronto lines for the latest transition captures are retained in the live
sniffer log stream at the timestamps above. Copy the complete line here whenever a capture
becomes a protocol fixture; do not infer missing values from a shortened chat excerpt.

### 14:34:51 — `n_sym=104`

```text
0000 006D 0034 0000 003E 0014 0005 000B 0046 0008 0045 0083 0008 005B 000B 005A 0009 0028 000D 008A 000B 0026 000C 0029 000A 0028 000B 0025 000D 0026 000B 0057 000E 002A 0008 0059 000A 0028 000A 0028 000C 0061 0004 0059 000B 005E ...
```

The line is intentionally marked incomplete here because the live log output was split
across multiple lines. It must be copied from the full log before use as a decoder fixture.

## Controlled FAN campaign — 16:18–16:23

The remote displayed FAN mode, a 23°C setpoint, and 24°C ambient temperature.
Home Assistant retained every ESPHome `on_raw` payload. The complete 22-packet
artifact, including repeats and one non-canonical packet, is
`fan-campaign-2026-08-15.jsonl`.

| Operator state | Timestamp | Decoded canonical frame | Result |
|---|---|---|---|
| AUTO | 16:18:59 | `D0 29 C8 18 03 51` | Confirmed; subsequent automatic cycle emitted FAN 1, 2, 5, 6, then AUTO |
| FAN 1 | 16:20:48 | `D0 29 CC 18 03 55` | Confirmed |
| FAN 2 | 16:21:16 | `D0 29 CA 18 03 53` | Confirmed |
| FAN 3 | 16:21:52 | `D0 29 CE 18 03 57` | Confirmed |
| FAN 4 | 16:22:11 | `D0 29 C9 18 03 50` | Confirmed; identical repeat at 16:22:21 |
| FAN 5 | 16:22:38 | `D0 29 CD 18 03 54` | Confirmed; first attempt arrived after the initial HA query |
| FAN 5 retry | 16:23:00 | `D0 29 CB 18 03 52` | Operator retry coincided with FAN 6; followed by a full automatic cycle |
| FAN 6 | 16:23:35 | `D0 29 CB 18 03 52` | Confirmed independently |

The controlled single-level captures establish the B2 low-nibble mapping:
AUTO=`8`, FAN1=`C`, FAN2=`A`, FAN3=`E`, FAN4=`9`, FAN5=`D`, FAN6=`B`.

The campaign also corrects the checksum model. All FAN frames validate with the
general formula
`reverseBits8(reverseBits8(B1) + reverseBits8(B2) + reverseBits8(B3) + 0xCB)`
modulo 256. The earlier ambient-based expression was a COOL-only algebraic
reduction and cannot validate other modes.

## Native Home Assistant implementation validation — 16:53–16:59

The XIAO firmware was built with the live ESPHome instance builder and flashed
over OTA. Home Assistant 2026.8.1 loaded one MQTT climate entity with
`fan_only` and custom fan modes `auto`, `1` through `6`. The room sensor read
25°C and the restored setpoint was 21°C.

| HA command | Captured frame | Physical observation |
|---|---|---|
| FAN AUTO | `D0 A9 88 18 03 91` | Accepted; beep |
| FAN 1 | `D0 A9 8C 18 03 95` | Beep; minimum airflow |
| FAN 2 | `D0 A9 8A 18 03 93` | Beep; airflow increased |
| FAN 3 | `D0 A9 8E 18 03 97` | Beep; airflow difference inconclusive |
| FAN 4 | `D0 A9 89 18 03 90` | Beep; fan audibly stronger |
| FAN 5 | `D0 A9 8D 18 03 94` | Beep; fan audibly stronger |
| FAN 6 | `D0 A9 8B 18 03 92` | First attempt not acknowledged; explicit resend at 16:58:04 beeped and produced maximum airflow |
| Return to COOL | `D0 AC 8B 18 03 97` | Beep; AC started |
| Initial OFF | `D0 AC 8B 08 03 87` | Beep, but AC remained in COOL; state-dependent OFF rejected semantically |
| Fixed OFF resend | `D0 AC A8 08 03 A4` | Beep; AC stopped |

The initial FAN 6 miss was not a frame-generation error: the sniffer captured
the expected frame. The identical explicit resend was accepted, so no automatic
repeat was added without broader reliability evidence.

OFF must always use the original remote's fixed frame. An OFF frame assembled
from the current setpoint and fan level can pass checksum validation and produce
a beep without stopping the unit. The firmware now returns the fixed
`D0 AC A8 08 03 A4` frame whenever `power=false`.

The Home Assistant automation also filters climate attribute changes: only HVAC
mode, target temperature, or fan mode changes emit IR. A retained ambient-
temperature MQTT update was verified not to trigger the automation or a new
sniffer capture.

## Current conclusions

1. The canonical control frame is 48 bits / `n_sym=99` and is validated for COOL and OFF.
2. Mode or state transitions can emit additional packet classes (`000D`, `n_sym=82`, `n_sym=104`) before a canonical frame.
3. FAN levels AUTO and 1–6 are now mapped from complete canonical captures.
4. The general checksum includes B1; the previous checksum expression is valid only for COOL.
5. Commit `931b3eb` implements the seven FAN levels and fixed OFF frame in the
   repository; the matching files were deployed, built with the live ESPHome
   instance, flashed over OTA, and physically validated as recorded above.
   Periodic auxiliary packets from the original remote remain separate future
   protocol work.

## Piste A phase 9 completion — 17:34–17:39

The remaining live-appliance tests used the Home Assistant climate path, except
for explicit identical-frame resends through the ESPHome service. DRY at 21°C
was acknowledged with a beep and produced behavior distinct from cooling and
fan-only operation. HVAC AUTO at 21°C was acknowledged, and changing its
setpoint to 22°C through Home Assistant produced another acknowledged command.

Identical AUTO/22°C/FAN AUTO commands were then used to characterize practical
reception cadence. The appliance acknowledged 9 of 10 commands at two-second
spacing and 8 of 10 at three-second spacing. At five-second spacing, Florent
observed 10 of 10 beeps. Fast identical commands therefore appear subject to an
appliance acknowledgement or reception window; normal human interaction is
reliable, and no automatic frame repeat was added.

The final Home Assistant command restored COOL at 22°C with FAN AUTO. Home
Assistant reported the same state, and the appliance acknowledged it with a
beep and resumed visibly cold airflow. Combined with the earlier FAN AUTO/1–6
and fixed-OFF tests, this completes the external-IR Piste A live validation for
COOL, DRY, FAN, AUTO, temperature changes, OFF, and practical repeatability.

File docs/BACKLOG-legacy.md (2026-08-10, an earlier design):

# BACKLOG — esphome-technibel-scdf32

## Priorité haute

- [ ] **Tester les 5 modes end-to-end** depuis HA : off / cool / dry / fan_only / auto
  + variations consigne (16–30°C) + vitesse fan (auto/low/med/high)
  → jamais validé depuis la session de reverse engineering (mai 2026)

- [ ] **IP statique pour l'ESP32** : réservation DHCP par adresse MAC dans le routeur
  → l'ESP était hors-ligne plusieurs jours suite à un changement d'IP (192.168.2.156 obsolète)

## Priorité moyenne

- [ ] **Installation permanente** : souder le circuit discret (TSAL6400 + 2N2222 + résistances),
  trouver le bon angle vers le récepteur IR de la clim, mettre en boîtier
  → câblage Dupont actuel fragile, angle ±17° critique

- [ ] **Aligner les YAMLs ESPHome** : la config production (`ir-clim-sniffer.yaml` dans ESPHome docker)
  a des options framework en plus (`minimum_chip_revision: 3.1`, `sram1_as_iram: true`)
  absentes du repo GitHub (`ir-technibel-clim.yaml`) → synchroniser

- [ ] **Renommer `ir-clim-sniffer.yaml`** dans ESPHome dashboard → `ir-technibel-clim.yaml`
  pour éviter la confusion (le fichier contient la config émetteur, pas le sniffer)

## Priorité basse / idées

- [ ] **Multi-LED** : ajouter une 2e TSAL6400 en parallèle (47Ω propre par LED)
  pour élargir le cône de couverture si le placement fixe reste sensible à l'angle
  → voir `docs/wiring.md` section "Optional: multiple LEDs"

- [ ] **Automations de confort** : horaires, seuils température (ex : cool auto à 17h30 si T° > 25°C)
  → à écrire dans `/homeassistant/packages/clim_sejour.yaml` quand le montage est finalisé

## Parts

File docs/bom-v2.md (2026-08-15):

# Technibel IR V2 — Liste de matériel

Cette nomenclature couvre la validation de la **Piste A** (émission IR externe),
la réalisation d'un montage de référence durable et une partie du matériel pouvant
être utile à la **Piste B1** (injection sur la ligne du récepteur IR).

Les références indiquées sont des références fabricant exactes et traçables. Elles
peuvent être commandées chez Mouser France ou recherchées à l'identique chez Farnell,
RS ou un autre distributeur agréé.

> Ne pas acheter le circuit d'interface B1 définitif avant d'avoir identifié le
> récepteur IR, le niveau logique, son type de sortie et l'isolation électrique de
> la carte du climatiseur.

## 1. Commande principale — reçue

The complete main order below was received from Mouser on 2026-08-14. These parts are
the known-origin reference stock for the V2 validation. Keep them identifiable as
Mouser parts; record only `Mouser`, `AliExpress`, or `legacy/unknown stock` in test
results rather than maintaining a separate inventory system.

| Qté | Fonction | Fabricant | Référence fabricant | Référence Mouser | Caractéristiques | Usage |
|---:|---|---|---|---|---|---|
| 10 | Résistance LED IR | Vishay / BC Components | `MRS25000C4709FRP00` | `594-MRS25000C4709FRP` | 47 Ω, 1 %, 0,6 W, traversante | Piste A |
| 5 | Charge de test 5 V | Vishay / BC Components | `MRS25000C1000FRP00` | `594-MRS25000C1000FRP` | 100 Ω, 1 %, 0,6 W, traversante | Validation |
| 20 | Résistance de base BC337 | Yageo | `MFR-50SFRF52-470R` | `603-MFR-50SFRF52470R` | 470 Ω, 1 %, 0,5 W, AEC-Q200 | A et B1 |
| 20 | Résistance LED visible | Yageo | `MFR-25FBF52-330R` | `603-MFR-25FBF52-330R` | 330 Ω, 1 %, 0,25 W | Validation |
| 20 | Pull-down base-émetteur | Yageo | `MFR-25FBF52-10K` | `603-MFR-25FBF52-10K` | 10 kΩ, 1 %, 0,25 W | A et B1 |
| 10 | Pull-up éventuel | Yageo | `MFR-25FBF52-4K7` | `603-MFR-25FBF52-4K7` | 4,7 kΩ, 1 %, 0,25 W | B1 conditionnel |
| 10 | Protection/test signal | Yageo | `MFR-25FBF52-1K` | `603-MFR-25FBF52-1K` | 1 kΩ, 1 %, 0,25 W | B1 conditionnel |
| 20 | Découplage local | Vishay / BC Components | `K104K15X7RF5TL2` | `594-K104K15X7RF5TL2` | 100 nF, 50 V, X7R, radial | A et B1 |
| 10 | Réservoir alimentation | Panasonic | `EEU-FR1E101` | `667-EEU-FR1E101` | 100 µF, 25 V, 105 °C, low ESR | A et B1 |
| 10 | Diode Schottky alimentation | Vishay | `1N5817-E3/54` | `625-1N5817-E3` | 1 A, traversante | Alimentation conditionnelle |
| 10 | Diode Schottky signal | Vishay | `BAT41-TR` | `78-BAT41` | 100 V, 100 mA, DO-35 traversant | B1 conditionnel |
| 10 | Transistor NPN authentique | onsemi | `BC33740BU` | `512-BC33740BU` | BC337-40, 45 V, 800 mA, TO-92, conditionnement vrac | Référence A et B1 |
| 10 | LED IR authentique | Vishay | `TSAL6400` | `782-TSAL6400` | 940 nm, angle ±25°, traversante | Piste A |

Brochage canonique du `BC33740BU` onsemi, face plate vers soi et pattes vers le bas :
**C-B-E** de gauche à droite (broche 1 collecteur, broche 2 base, broche 3 émetteur),
conformément à la fiche technique onsemi `BC337-FSC/D`. Ne pas lui appliquer le brochage
d'un autre transistor en boîtier TO-92.

### Pourquoi conserver des composants authentiques de référence

Les BC337-40 et TSAL6400 déjà disponibles peuvent être utilisés pour comparaison. Les
composants Mouser servent cependant d'étalons : en cas d'échec, ils
permettent d'écarter rapidement un faux marquage, un mauvais brochage ou un composant
hors spécification.

Les phases 2 à 9 sont réalisées sur breadboard. Les composants de référence ne sont
soudés sur la carte Piste A durable qu'en phase 10, après validation réelle sur la
climatisation.

### Dimensionnement important

- La résistance de `47 Ω` est réservée à la TSAL6400 alimentée en 5 V.
- Utiliser une puissance nominale d'au moins 0,5 W pour la résistance de `47 Ω`.
- Ne pas utiliser `47 Ω` avec une LED visible standard ; utiliser `330 Ω`.
- La résistance de charge `100 Ω / 0,6 W` dissipe environ 0,25 W sous 5 V.
- Placer un `100 nF` au plus près de l'alimentation du XIAO.
- Placer un `100 nF` et un `100 µF` près du driver IR.
- Respecter la polarité du condensateur électrolytique.

## 2. Connectique JST-XH

Pour les liaisons basse tension nécessitant un connecteur démontable :

| Qté | Élément | Fabricant | Référence fabricant |
|---:|---|---|---|
| 5 | Embase PCB verticale, 2 positions | JST | `B2B-XH-A-BK(LF)(SN)` |
| 5 | Boîtier femelle, 2 positions | JST | `XHP-2` |
| 20 | Contact femelle pour fil | JST | `SXH-002T-P0.6` |

Un sertissage mal réalisé est moins fiable qu'une soudure correcte. Utiliser une pince
adaptée aux contacts JST-XH ou acheter des fils présertis. Pour une installation
permanente, ajouter un soulagement de traction ; le connecteur ne doit pas reprendre
les efforts mécaniques du câble.

## 3. Alimentation USB de test

Utiliser une alimentation USB-C stable et authentique, capable de fournir au moins
500 mA. Une alimentation de 1 A ou plus donne une marge confortable pour les pointes
de courant Wi-Fi.

Exemple robuste :

| Qté | Produit | Référence | Caractéristiques |
|---:|---|---|---|
| 1 | Alimentation officielle Raspberry Pi USB-C EU | `SC0873` | 5,1 V, 3 A, prise européenne |

Prévoir également un câble USB-C **de données** fiable et identifié pour le flash.
Ne pas utiliser le module MB102 comme alimentation de référence lors d'un diagnostic.

## 4. Conversion 12 V vers 5 V — achat anticipé facultatif

Si la clim ne fournit qu'un rail basse tension de 12 V, un convertisseur industriel
est préférable à un module ajustable sans marque.

| Qté | Fabricant | Référence fabricant | Entrée | Sortie | Remarque |
|---:|---|---|---|---|---|
| 2 | TRACO Power | `TSR 1-2450` | 6,5–36 V CC | 5 V / 1 A | SIP-3, non isolé |

> Le `TSR 1-2450` est **non isolé**. Il ne doit être utilisé que si le rail qui
> l'alimente a déjà été identifié comme une basse tension sûre et correctement isolée
> du secteur. Il ne rend pas une alimentation dangereuse sûre.

Ne pas installer ce convertisseur avant d'avoir mesuré la tension réelle et vérifié
la capacité du rail interne.

## 5. Matériel mécanique

Les dimensions exactes dépendront de l'emplacement retenu, mais prévoir :

- gaine thermorétractable 2:1 : 1,6 mm, 3,2 mm et 6,4 mm ;
- entretoises nylon M2 ou M2.5 : hauteurs 6 mm et 10 mm ;
- vis et écrous nylon assortis ;
- colliers polyamide et embases de retenue ;
- petit boîtier isolant à brides, environ 60 × 40 × 20 mm ;
- passe-fil ou serre-câble ;
- mini-grabbers isolés pour les mesures basse tension ;
- plaque à pastilles étamées double face de bonne qualité ;
- supports femelles 7 contacts, pas 2,54 mm, si les supports actuels maintiennent mal le XIAO.

Dans la clim, ne pas compter sur un adhésif seul. La carte doit être fixée
mécaniquement, protégée des parties conductrices, des vibrations, de la condensation,
des moteurs et du câblage secteur.

## 6. Matériel déjà disponible et réutilisable

D'après l'inventaire du projet :

- Seeed XIAO ESP32-C3 ;
- Seeed XIAO ESP32-C6 comme solution de repli ;
- BC337-40 ;
- TSAL6400 ;
- résistances 47 Ω, 330 Ω et 470 Ω ;
- LED visibles ;
- KY-022 / VS1838B ;
- analyseur logique USB 24 MHz ;
- multimètre ;
- plaques FR4 ;
- fil silicone 22/24 AWG ;
- headers 2,54 mm ;
- breadboards ;
- matériel de soudure.

Avant de commander, vérifier les résistances déjà disponibles au multimètre et lire
leur puissance nominale. Les résistances `47 Ω` de 0,25 W restent utilisables pour des
essais brefs, mais pas comme choix final avec la TSAL6400 à environ 74 mA.

## 7. Achats à différer jusqu'à l'inspection de la clim

Ne pas choisir avant la caractérisation de la carte :

- optocoupleur ;
- isolateur numérique ;
- buffer ou porte logique ;
- convertisseur DC/DC isolé ;
- valeur définitive du pull-up de la ligne IR ;
- circuit wired-OR définitif ;
- connecteur correspondant à la carte de la clim ;
- équipement de mesure isolé spécialisé.

Le choix dépendra de :

1. l'isolation réelle de la logique par rapport au secteur ;
2. la tension d'alimentation du récepteur IR ;
3. la tension de la ligne Signal côté MCU ;
4. la topologie de sortie du récepteur IR ;
5. la tension et la capacité du rail utilisé pour alimenter le XIAO.

## 8. Liens de vérification

- [Vishay MRS25 — 47 Ω, 0,6 W](https://www.mouser.fr/ProductDetail/Vishay-BC-Components/MRS25000C4709FRP00)
- [Vishay MRS25 — 100 Ω, 0,6 W](https://www.mouser.fr/ProductDetail/Vishay-BC-Components/MRS25000C1000FRP00)
- [Yageo 10 kΩ, 0,25 W, 1 %](https://www.mouser.fr/fr/ProductDetail/YAGEO/MFR-25FBF52-10K)
- [Yageo MFR-50SFRF52-470R — 470 Ω, 0,5 W, 1 %, AEC-Q200](https://www.mouser.fr/ProductDetail/YAGEO/MFR-50SFRF52-470R)
- [Vishay 100 nF, 50 V, X7R](https://www.mouser.fr/ProductDetail/Vishay-BC-Components/K104K15X7RF5TL2)
- [Panasonic FR 100 µF, 25 V](https://www.mouser.fr/fr/ProductDetail/Panasonic/EEU-FR1E101)
- [onsemi BC33740BU — BC337-40 traversant](https://www.mouser.fr/ProductDetail/onsemi/BC33740BU)
- [Vishay BAT41-TR — Schottky signal traversante](https://www.mouser.fr/ProductDetail/Vishay-Semiconductors/BAT41-TR)
- [Vishay TSAL6400](https://www.mouser.fr/ProductDetail/Vishay-Semiconductors/TSAL6400)
- [JST série XH](https://www.mouser.fr/c/connectors/?series=XH)
- [TRACO Power TSR 1-2450](https://www.mouser.fr/ProductDetail/TRACO-Power/TSR-1-2450)

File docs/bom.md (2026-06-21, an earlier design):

# Bill of Materials / Liste de matériel

**[🇬🇧 English](#-english)** · **[🇫🇷 Français](#-français)**

---

## 🇬🇧 English

### Transmitter (final build)

| Component | Reference | Role | Notes |
|---|---|---|---|
| MCU | ESP32 DevKit 30-pin | Main controller | Any ESP32 board works |
| IR LED | TSAL6400 (5mm, 940nm) | IR emission | Narrow angle ±17° — if aiming at the AC receiver is difficult, use a wide-angle 940nm LED (±45°) instead |
| Transistor | 2N2222 NPN (TO-92) | LED driver | BC337 also works |
| Resistor | 47Ω (with 5V) or **22Ω (with 3.3V)** | LED current limiting | See wiring note on ESP32 Vin |
| Resistor | 470Ω | Transistor base | 330Ω–560Ω acceptable |
| Cables | Dupont M/M + M/F | Wiring | 5 connections total |
| Enclosure | Any | Optional | Protects the ESP32 |

### Sniffer (capture phase only — not needed in final build)

| Component | Reference | Role | Notes |
|---|---|---|---|
| IR receiver | KY-022 / VS1838B (38kHz) | Capture raw IR frames | Frequency must be 38kHz |
| Cables | Dupont M/F | Wiring | 3 wires: 3V3, GND, GPIO23 |

> The sniffer is used only during the reverse engineering phase to capture frames
> from the original Technibel remote control. It is not needed in the final installation.

### Sourcing tips

- **TSAL6400**: available on AliExpress and Amazon. Search "TSAL6400 940nm IR LED". Any 940nm 5mm IR emitter is a drop-in substitute. Note: the ±17° angle requires precise aiming at the AC receiver window — if space is tight, prefer a wide-angle 940nm LED (±45°–60°).
- **2N2222**: included in most BJT transistor assortment kits. BC337 is a common alternative.
- **KY-022**: standard Arduino sensor kit component, available everywhere.
- **ESP32 DevKit**: any 30-pin or 38-pin ESP32 board works.

---

## 🇫🇷 Français

### Émetteur (montage final)

| Composant | Référence | Rôle | Notes |
|---|---|---|---|
| MCU | ESP32 DevKit 30 broches | Contrôleur principal | Tout ESP32 fonctionne |
| LED IR | TSAL6400 (5mm, 940nm) | Émission IR | Angle étroit ±17° — si viser le récepteur de la clim est difficile, préférer une LED 940nm grand angle (±45°) |
| Transistor | 2N2222 NPN (TO-92) | Driver LED | BC337 convient aussi |
| Résistance | 47Ω (avec 5V) ou **22Ω (avec 3.3V)** | Limitation courant LED | Voir note câblage sur le pin Vin ESP32 |
| Résistance | 470Ω | Base transistor | 330Ω–560Ω acceptables |
| Câbles | Dupont M/M + M/F | Câblage | 5 connexions au total |
| Boîtier | Au choix | Optionnel | Protège l'ESP32 |

### Sniffer (phase de capture uniquement — inutile dans le montage final)

| Composant | Référence | Rôle | Notes |
|---|---|---|---|
| Récepteur IR | KY-022 / VS1838B (38kHz) | Capturer trames IR brutes | Fréquence obligatoirement 38kHz |
| Câbles | Dupont M/F | Câblage | 3 fils : 3V3, GND, GPIO23 |

> Le sniffer n'est utilisé que pendant la phase de reverse engineering pour capturer
> les trames de la télécommande Technibel originale. Il n'est pas nécessaire dans l'installation finale.

### Conseils d'achat

- **TSAL6400** : disponible sur AliExpress et Amazon. Chercher "TSAL6400 940nm IR LED". Toute LED IR 940nm 5mm est interchangeable. Attention : l'angle ±17° impose un viser précis sur le récepteur de la clim — si l'espace est contraint, préférer une LED grand angle 940nm (±45°–60°).
- **2N2222** : inclus dans la plupart des kits de transistors BJT. BC337 est une alternative courante.
- **KY-022** : composant standard des kits capteurs Arduino, disponible partout.
- **ESP32 DevKit** : tout board 30 ou 38 broches convient.

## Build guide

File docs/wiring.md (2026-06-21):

# Wiring / Câblage

**[🇬🇧 English](#-english)** · **[🇫🇷 Français](#-français)**

---

## 🇬🇧 English

### Transmitter wiring (final build)

```
ESP32                  Discrete IR circuit
─────                  ──────────────────
3V3       ──[22Ω]────► Anode (+, long leg)  TSAL6400
                        Cathode (−, short leg) ──► Collector (right pin)  ┐
                                                    2N2222 NPN              │
GPIO4     ──[470Ω]───► Base (middle pin)     ──────────────────────────────┤
                        Emitter (left pin)   ──────────────────────────────┘
GND       ◄────────────────────────────────────────────────────────────────┘
```

**2N2222 TO-92 pinout** (flat face toward you, pins pointing down):
```
Left = Emitter (E) · Middle = Base (B) · Right = Collector (C)
```

> **⚠️ Vin vs 3V3:** Many ESP32 DevKit boards do **not** expose USB 5V on the Vin pin —
> Vin reads 0V when powered via USB. Use the **3V3 pin** instead and reduce the LED
> resistor from 47Ω to **22Ω** to compensate (target current ~80mA peak).
> If your board does supply 5V on Vin, keep 47Ω.

> **Note:** Solder or use a small breadboard for reliable connections — Dupont wires
> on bare component leads are fragile in long-term installation.

### Sniffer wiring (capture phase only)

```
ESP32                  KY-022 / VS1838B (IR RX)
─────                  ────────────────────────
3V3       ────────────► VCC (S pin on KY-022 carrier board)
GND       ────────────► GND
GPIO23    ◄──────────── OUT (signal pin)
```

> **Note:** The KY-022 signal output is active-low. The ESPHome config uses
> `inverted: true` on the pin to compensate.

### Combined wiring (sniffer + transmitter on same ESP32)

Both circuits can coexist on the same ESP32 during the capture phase:

```
ESP32 GPIO4  ──[470Ω]──► Base 2N2222 / [47Ω] ──► TSAL6400    (TX)
ESP32 GPIO23 ◄────────── KY-022 OUT                            (RX)
ESP32 5V     ──────────► TSAL6400 via 47Ω resistor
ESP32 3V3    ──────────► KY-022 VCC
ESP32 GND    ──────────► 2N2222 Emitter + KY-022 GND (common ground)
```

### Optional: multiple LEDs for wider coverage angle

The TSAL6400 has a narrow ±17° emission angle. Adding 2–3 LEDs in parallel, each
pointed at a slightly different angle, widens the coverage cone without changing the
ESP32 wiring or firmware.

```
                    ┌──[47Ω]──► LED1 anode (+) → cathode ──┐
5V ─────────────────┤                                        ├──► Collector (2N2222)
                    └──[47Ω]──► LED2 anode (+) → cathode ──┘
GPIO4 ──[470Ω]──► Base
GND  ◄─────────── Emitter
```

> Each LED must have its own series resistor (47Ω each) to balance current.
> Do not share a single resistor across parallel LEDs.
> With 2× TSAL6400: ~70mA peak per LED, well within 2N2222 limits (600mA total).

### Final installation tips

- Mount the ESP32 + Diymore module close to the AC indoor unit.
- Point the IR LED toward the AC receiver window (usually on the front panel).
- Power via USB (5V / 500mA minimum) or a 5V wall adapter.
- The IR signal is directional — test range and angle before finalizing placement.

---

## 🇫🇷 Français

### Câblage émetteur (montage final)

```
ESP32                  Circuit IR discret
─────                  ──────────────────
3V3       ──[22Ω]────► Anode (+, longue patte)  TSAL6400
                        Cathode (−, courte patte) ──► Collector (patte droite)  ┐
                                                       2N2222 NPN                │
GPIO4     ──[470Ω]───► Base (patte milieu)       ──────────────────────────────┤
                        Emitter (patte gauche)    ──────────────────────────────┘
GND       ◄─────────────────────────────────────────────────────────────────────┘
```

**Brochage 2N2222 TO-92** (face plate vers toi, pattes vers le bas) :
```
Gauche = Emitter (E) · Milieu = Base (B) · Droite = Collector (C)
```

> **⚠️ Vin vs 3V3 :** Sur de nombreux ESP32 DevKit, le pin Vin ne fournit **pas** le 5V USB —
> il mesure 0V quand la carte est alimentée via USB. Utiliser le pin **3V3** à la place et
> réduire la résistance LED de 47Ω à **22Ω** pour compenser (courant cible ~80mA crête).
> Si ton board fournit bien 5V sur Vin, garder 47Ω.

> **Note :** Souder ou utiliser une mini breadboard pour un montage fiable — les fils
> Dupont sur les pattes nues des composants sont fragiles pour une installation permanente.

### Câblage sniffer (phase de capture uniquement)

```
ESP32                  KY-022 / VS1838B (IR RX)
─────                  ────────────────────────
3V3       ────────────► VCC (broche S sur le module KY-022)
GND       ────────────► GND
GPIO23    ◄──────────── OUT (broche signal)
```

> **Note :** La sortie signal du KY-022 est active bas. La config ESPHome utilise
> `inverted: true` sur la broche pour compenser.

### Câblage combiné (sniffer + émetteur sur le même ESP32)

Les deux circuits peuvent coexister sur le même ESP32 pendant la phase de capture :

```
ESP32 GPIO4  ──[470Ω]──► Base 2N2222 / [47Ω] ──► TSAL6400    (TX)
ESP32 GPIO23 ◄────────── KY-022 OUT                            (RX)
ESP32 5V     ──────────► TSAL6400 via résistance 47Ω
ESP32 3V3    ──────────► KY-022 VCC
ESP32 GND    ──────────► Emitter 2N2222 + KY-022 GND (masse commune)
```

### Optionnel : plusieurs LEDs pour élargir l'angle de couverture

La TSAL6400 a un angle d'émission étroit de ±17°. Ajouter 2–3 LEDs en parallèle,
chacune orientée légèrement différemment, élargit le cône sans modifier le firmware
ni le câblage ESP32.

```
                    ┌──[47Ω]──► LED1 anode (+) → cathode ──┐
5V ─────────────────┤                                        ├──► Collector (2N2222)
                    └──[47Ω]──► LED2 anode (+) → cathode ──┘
GPIO4 ──[470Ω]──► Base
GND  ◄─────────── Emitter
```

> Chaque LED doit avoir sa propre résistance série (47Ω chacune) pour équilibrer le courant.
> Ne pas partager une seule résistance entre plusieurs LEDs en parallèle.
> Avec 2× TSAL6400 : ~70mA crête par LED, largement dans les limites du 2N2222 (600mA total).

### Conseils d'installation finale

- Monter l'ESP32 + module Diymore à proximité de l'unité intérieure du climatiseur.
- Orienter la LED IR vers la fenêtre de réception de la clim (généralement sur le panneau avant).
- Alimenter via USB (5V / 500mA minimum) ou une alimentation murale 5V.
- Le signal IR est directionnel — tester la portée et l'angle avant de fixer définitivement.

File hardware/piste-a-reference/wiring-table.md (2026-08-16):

# Piste A perfboard wiring table

Coordinate convention: component-side view, USB-C toward row 1. The solder-side drawing is mirrored by KiCad.

| Wire | Net | Color | Side | From | To | Straight length |
|---|---|---|---|---|---|---:|
| W01 | `GPIO3` | YELLOW | solder side | `B3` | `A3` | 2.5 mm |
| W02 | `GPIO3` | YELLOW | solder side | `A3` | `A11` | 20.3 mm |
| W03 | `GPIO3` | YELLOW | solder side | `A11` | `B11` | 2.5 mm |
| W04 | `BASE` | YELLOW | solder side | `E11` | `E18` | 17.8 mm |
| W05 | `BASE` | YELLOW | solder side | `E18` | `E20` | 5.1 mm |
| W06 | `+3V3` | YELLOW | solder side | `H4` | `I4` | 2.5 mm |
| W07 | `GND` | BLACK | solder side | `H3` | `I3` | 2.5 mm |
| W08 | `GND` | BLACK | solder side | `I3` | `G3` | 5.1 mm |
| W09 | `GND` | BLACK | solder side | `F18` | `G18` | 2.5 mm |
| W10 | `GND` | BLACK | solder side | `H20` | `G20` | 2.5 mm |
| W11 | `+5V` | RED | component-side jumper | `H2` | `J2` | 5.1 mm |
| W12 | `+5V` | RED | solder side | `J2` | `J21` | 48.3 mm |
| W13 | `IR_ANODE` | YELLOW | solder side | `F21` | `F23` | 5.1 mm |
| W14 | `IR_CATHODE` | YELLOW | solder side | `D18` | `C18` | 2.5 mm |
| W15 | `IR_CATHODE` | YELLOW | solder side | `C18` | `C24` | 15.2 mm |
| W16 | `IR_CATHODE` | YELLOW | solder side | `C24` | `G24` | 10.2 mm |
| W17 | `IR_CATHODE` | YELLOW | solder side | `G24` | `G23` | 2.5 mm |
| W18 | `GND` | BLACK | solder side | `G3` | `G18` | 38.1 mm |
| W19 | `GND` | BLACK | solder side | `G18` | `I18` | 5.1 mm |
| W20 | `GND` | BLACK | solder side | `G18` | `G20` | 5.1 mm |
| W21 | `GND` | BLACK | solder side | `I17` | `I18` | 2.5 mm |
| W22 | `GND` | BLACK | solder side | `I18` | `I19` | 2.5 mm |
| W23 | `IR_ANODE` | YELLOW | solder side | `G21` | `F21` | 2.5 mm |

## Component coordinates

| Ref | Value | Pin coordinates |
|---|---|---|
| U1 | XIAO ESP32-C3, 2x7 sockets | pin 2/D1/GPIO3=`B3`; pin 8/5V=`H2`; pin 9/GND=`H3`; pin 10/3V3=`H4`; all 14 pins represented |
| R1 | 470 ohm | 2/GPIO3=`B11`; 1/BASE=`E11` |
| Q1 | BC33740BU | 1/C=`D18`; 2/B=`E18`; 3/E=`F18` |
| R2 | 10 kohm | 1/BASE=`E20`; 2/GND=`H20` |
| C1 | 100 nF | 2/GND=`I3`; 1/3V3=`I4` |
| C2 | 100 nF | 2/GND=`I17`; 1/5V=`J17` |
| C3 | 100 uF | 2/GND=`I19`; 1/+5V=`J19` |
| R3 | 47 ohm / 0.6 W | 1/5V=`J21`; 2/IR_ANODE=`G21` |
| D1 | fresh TSAL6400 | 2/A=`F23`; 1/K=`G23` |

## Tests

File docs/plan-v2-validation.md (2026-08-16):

# Technibel IR V2 — Step-by-step Validation Plan

## Context

### What exists

The Technibel SCDF32C5I air conditioner uses a proprietary 48-bit IR protocol at 38kHz,
not recognized by IRremoteESP8266. The protocol was fully reverse-engineered by capturing
frames from the original remote using an ESP32 + KY-022 TSOP receiver + ESPHome
`remote_receiver`. The result:

- `esphome/libraries/technibel_ir.h` — C++ IR frame builder (mode, temp, fan, power, checksum)
- `esphome/ir-technibel-clim.yaml` — ESPHome config with `remote_transmitter` and API service
- `docs/protocol.md` — full protocol documentation (frame structure, encoding, checksum formula)
- `docs/wiring.md` — hardware wiring (TSAL6400 + 2N2222 discrete circuit)
- `docs/control-strategies.md` — three installation strategies (A: external IR, B1: TSOP injection, B2: bus interception)

The protocol implementation is considered correct and stable. It will not be modified.

### What failed

The original prototype (ESP32 DevKit generic + 2N2222 + TSAL6400 on breadboard) never
reliably controlled the AC unit. Symptoms:

- IR LED invisible to smartphone camera (while the original remote IS visible)
- ESP32 DevKit lost its 5V output (3.3V still works)
- Multiple IR modules burned out
- Diagnosis: hardware chain failure (not software) — transistor pinout, wiring, or power issue

Root cause was never definitively identified because debugging was done blind (no logic
analyzer, mixed old/new components, breadboard contact issues).

### Available hardware

All components are now available:

| Component | Source | Qty | Status |
|---|---|---|---|
| Seeed XIAO ESP32-C3 | AliExpress (official Seeed store) | 3 | Received |
| Seeed XIAO ESP32-C6 | AliExpress | 1+ | Received |
| BC337-40 NPN (TO-92) | AliExpress | 100 | Received |
| TSAL6400 Vishay 940nm | AliExpress | 10+ | Received |
| USB Logic Analyzer 8ch 24MHz | AliExpress | 1 | Received |
| PCB FR4 double-sided (assorted) | AliExpress | 10 | Received |
| KY-022 / VS1838B IR receiver | Already owned | 1 | Working |
| Technibel original remote | Already owned | 1 | Working |
| Multimeter | Already owned | 1 | Working |
| Go Tronic GT1087 IR module | Go Tronic | 1 | Received |
| Resistors (47Ω, 470Ω, 330Ω, assorted) | Already owned + AliExpress | Many | Available |
| LED assortment (red, green, blue, yellow, white) | AliExpress | Kit | Received |
| Silicone wire 22/24 AWG (red, black, yellow) | AliExpress | 3×3m | Received |
| Soldering flux NC-559 | AliExpress | 1 | Received |
| Desoldering braid | AliExpress | 1 | Received |
| Headers male/female 2.54mm | AliExpress | Assorted | Received |
| Tact switches 6×6mm | AliExpress | 50 | Received |
| MB102 breadboard + power module | AliExpress | 2 | Received |
| Mouser reference components | Mouser | See `docs/bom-v2.md` | Received 2026-08-14 |

The Mouser order provides known-origin reference parts for the validation: Vishay
TSAL6400 emitters, onsemi BC33740BU transistors, the required resistors, decoupling
capacitors, reservoir capacitors, and conditional Schottky diodes. Exact manufacturer
and Mouser references are maintained in `docs/bom-v2.md`.

For every hardware gate, record only the component source needed to reproduce the
result: `Mouser`, `AliExpress`, or `legacy/unknown stock`. Prefer Mouser reference parts
for the main validation path. AliExpress or legacy parts remain useful for comparison
when diagnosing a failure; do not mix their results without recording the source.

Phases 2–9 are breadboard validation. Do not solder the validated Piste A circuit until
Phase 9 passes; soldering starts in Phase 10.

### Goals

1. **Piste A** — Validate external IR emission: ESP32 sends a frame, AC unit responds
2. **Piste B1** — Migrate to direct TSOP injection inside the AC unit (endgame)

Sequential: A first (proves protocol works end-to-end), then B1 (eliminates IR optics).
Piste A hardware is kept intact as a reference/fallback after B1 migration.

### Platform choice: XIAO ESP32-C3

Rationale:
- Seeed's own "XIAO IR Mate" product validates this exact use case (ESPHome + remote_transmitter + IR LED on GPIO3)
- ESPHome board: `seeed_xiao_esp32c3`, variant: `esp32c3`
- 5V pin available when powered via USB-C (USB voltage passthrough)
- RMT v2: 2 TX channels + 2 RX channels (dedicated), sufficient for IR TX
- Requires: `board_build.flash_mode: dio`, `logger.hardware_uart: UART0`
- GPIO3 (D1) for IR TX, GPIO4 (D2) for IR RX — proven by XIAO IR Mate

**IMPORTANT: ESP32-C3 GPIOs are NOT 5V-tolerant.** Maximum input voltage is 3.6V
(Espressif datasheet). This affects Phase 10 design — the GPIO must never be directly
exposed to a 5V signal line.

**Power budget**: the XIAO 5V pin is USB passthrough. WiFi produces current spikes
well above average draw. Use a USB power supply rated ≥500mA (not 200mA).
When powering from an internal AC rail, prevent simultaneous USB power (use a diode,
jumper, or explicit disconnect procedure before connecting USB for flashing/debug).

### Key constraint: protocol encoding is frozen

Frame encoding and checksum logic in `technibel_ir.h` do not change. Physical timing
constants may change only after an instrumented comparison with the original remote.
All other work is in YAML configuration and hardware.

---

## Plan: phases with gatekeepers

Each phase has a **gatekeeper** — a pass/fail test that must succeed before advancing.
If a gate fails, the failure action column tells you what to try. You never move forward
on a failed gate.

---

### Phase 1 — Flash a bare XIAO C3

**Goal**: prove the board boots, connects to WiFi, and responds on ESPHome API.

**Actions**:

1. Create or select `esphome/ir-technibel-clim-min.yaml` — minimal config (WiFi + logger + API + OTA, NO IR yet)
2. Required boilerplate for C3:
   ```yaml
   esp32:
     board: seeed_xiao_esp32c3
     variant: esp32c3
     framework:
       type: arduino

   esphome:
     name: ir-technibel-clim-min
     friendly_name: Clim Séjour IR Min
     platformio_options:
       board_build.flash_mode: dio

   logger:
     level: DEBUG
     hardware_uart: UART0

   ota:
     - platform: esphome
       password: !secret ota_password
   ```
3. Validate the YAML before touching the device: `esphome config esphome/ir-technibel-clim-min.yaml`.
4. Flash via USB-C from the ESPHome dashboard (`Install` → `Plug into this computer`) or with
   `esphome run esphome/ir-technibel-clim-min.yaml`; USB is required for the first flash.
5. Check ESPHome logs: boot OK, WiFi connected, API accessible. Subsequent firmware updates
   may use OTA after the device has completed its first successful boot.

**Minimum ESPHome version**: 2024.6+ recommended for RMT v2 support on C3.

**Gatekeeper 1**:

| Test | Pass | Fail action |
|---|---|---|
| Board visible in ESPHome dashboard | Continue | Check USB cable, try another port, verify flash_mode: dio |
| Logs show "WiFi connected" | Continue | Check SSID/password in secrets |
| API accessible from HA | Continue | Check network, firewall |

---

### Phase 2 — GPIO toggle: prove the pin works

**Goal**: verify GPIO3 (D1) toggles correctly, with NO IR components. Just a visible LED.

**Actions**:

1. Solder two 1×7 **male pin headers** onto the XIAO C3, with the long pins pointing down,
   so the board can plug into and later be removed from a breadboard. Female Dupont wires
   alone do not make the XIAO pluggable into a breadboard.
2. Wire a **red visible LED** + **330Ω** between GPIO3 and GND (direct, no transistor)
   - I = (3.3V − 2.0V) / 330Ω ≈ 4mA — safe for any standard LED
   - Do NOT use 47Ω here — that resistor is sized for the TSAL6400 on a 5V rail
3. Patch `esphome/ir-technibel-clim-min.yaml` with this test block (a GPIO `switch` is used
   because `output.toggle` is not a valid ESPHome action):
   ```yaml
   switch:
     - platform: gpio
       pin: GPIO3
       id: test_gpio
       restore_mode: ALWAYS_OFF

   interval:
     - interval: 500ms
       then:
         - switch.toggle: test_gpio
   ```
4. Validate the patched YAML, then flash it (USB if this is the first firmware containing
   this device identity; otherwise OTA is acceptable):
   `esphome config esphome/ir-technibel-clim-min.yaml`
   `esphome run esphome/ir-technibel-clim-min.yaml`
5. Observe the red LED: it must blink at ~1Hz. Measure GPIO3 against GND; it must alternate
   between approximately 0V and 3.3V. Do not measure resistance or continuity on a powered board.

**Gatekeeper 2**:

| Test | Pass | Fail action |
|---|---|---|
| Red LED blinks at ~1Hz | GPIO3 works | Try GPIO4 (D2), check solder joints |
| Multimeter GPIO3: alternates 0V ↔ 3.3V | Confirmed | Wrong pin number or dead pin |

After validation: record the measured values and component provenance, then remove the test
YAML block (`switch` + `interval`) before proceeding to Phase 4.

---

### Phase 3 — Power: confirm 5V rail

**Goal**: prove the XIAO 5V pin delivers ~5V when USB-C powered.

**Actions**:

1. Plug XIAO via USB-C to a good charger (≥500mA, ideally ≥1A)
2. Multimeter DC between the `USB`/`VBUS` pin and GND. On some XIAO ESP32-C3
   revisions the pin is silk-screened `USB` rather than `5V`; it is the USB-C
   5 V rail, not the regulated `3V3` output.
3. Load test: use a 100Ω resistor rated ≥0.5W (I=50mA, P=0.25W).
   Do NOT use 47Ω directly between 5V and GND: I=106mA, P=0.53W → exceeds ¼W rating.
   The real load test happens naturally in Phase 6 when the TSAL6400 circuit draws ~74mA.

**Gatekeeper 3**:

| Test | Pass | Fail action |
|---|---|---|
| Multimeter reads 4.8V – 5.2V | 5V rail OK | Try different USB-C cable, try stronger charger |
| Stable under load | Supply OK | Charger too weak |

---

### Phase 4 — Transistor: validate BC337-40 in isolation

**Goal**: confirm BC337-40 pinout and function BEFORE integrating into the circuit.

**Actions**:

1. Take a fresh onsemi BC33740BU from the Mouser reference lot
2. **Verified pinout for the onsemi `BC33740BU` reference part** (flat face toward you,
   pins pointing down): C (left, pin 1) – B (middle, pin 2) – E (right, pin 3).
   This C-B-E order comes from the onsemi `BC337-FSC/D` datasheet and is the canonical
   orientation for the Mouser reference lot. Do not reuse the E-B-C orientation of a
   different TO-92 transistor. If an AliExpress or otherwise substituted transistor is
   tested for comparison, record its source and determine its actual pinout separately.
3. Multimeter diode mode to identify Base (the pin that shows ~650mV to both others):

   | Red probe | Black probe | Expected (NPN) |
   |---|---|---|
   | Base | Emitter | ~600–700 mV |
   | Base | Collector | ~600–700 mV |
   | Any other combination | | OL (open) |

   This identifies Base reliably but does NOT distinguish Collector from Emitter.

4. **Switching test**:
   - For the onsemi `BC33740BU` reference part, wire the datasheet C-B-E orientation
     directly; a second reversed C/E test is not required to rediscover its documented pinout.
   - For an unknown-source or substituted transistor, test both orientations to identify C vs E:
     - Orientation A: 3.3V → 470Ω → Base, 5V → **330Ω** → Red LED → pin X (presumed Collector), pin Y → GND
     - Orientation B: swap pin X and pin Y
     - Measure VCE (voltage between Collector candidate and Emitter candidate) in both orientations.
       The correct orientation gives lower VCE (deeper saturation, ~0.1–0.2V).
       Inverted orientation gives higher VCE (~0.5–1V) because the transistor operates in reverse mode.
   - If multimeter has hFE function: use it to confirm C/E directly

**Gatekeeper 4**:

| Test | Pass | Fail action |
|---|---|---|
| Diode mode: ~650mV from Base to both others | Base identified | Not NPN — discard, try another |
| onsemi `BC33740BU` wired C-B-E and VCE < 0.3V when ON | C/E orientation and switching confirmed | Recheck the flat-face reference and wiring against the onsemi datasheet |
| Unknown-source substitute: one orientation has VCE < 0.3V, the other > 0.5V | C/E identified | Both similar → try another transistor |
| LED OFF when Base disconnected | No leakage | Short circuit — discard transistor |

---

### Phase 5 — Full chain on breadboard: GPIO → BC337 → visible LED

**Goal**: prove the complete chain ESP → resistor → transistor → LED works with the toggle YAML.

**Wiring**:

```
XIAO C3              Circuit
─────────             ──────
5V  ──────[330Ω]───► Anode (+) RED LED ──► Cathode (−) ──► Collector BC337
GPIO3 ──[470Ω]──┬─► Base BC337
                │
              [10kΩ]   ← pull-down: keeps BC337 OFF during ESP32 boot
                │
GND  ◄──────────┴──── Emitter BC337
```

Notes:
- **330Ω** for visible LED test (I ≈ (5−2−0.2)/330 ≈ 8.5mA — safe for any 5mm LED)
- **10kΩ base-emitter pull-down**: ensures transistor stays OFF when GPIO floats at boot
- The 47Ω resistor is reserved for the TSAL6400 (Phase 6)

**Actions**:

1. Wire on breadboard with the **red visible LED** (NOT the TSAL6400 yet)
2. Restore the 1Hz toggle YAML from Phase 2
3. Red LED must blink through the transistor

**Gatekeeper 5**:

| Test | Pass | Fail action |
|---|---|---|
| Red LED blinks via transistor at 1Hz | Full chain OK | Multimeter on Base (~0.7V when ON), Collector (~0.2V when ON) |
| Collector voltage during ON: < 0.5V | BC337 saturates properly | Base resistor too high, or wrong C/E orientation |
| LED stays OFF at ESP32 boot (before GPIO init) | Pull-down works | Check 10kΩ connection |

---

### Phase 6 — Swap in TSAL6400

**Goal**: same circuit, same YAML, but replace visible LED with IR LED and use correct resistor.

**Actions**:

1. Replace red LED with a fresh TSAL6400 (anode = long leg toward resistor, cathode toward Collector)
2. Replace 330Ω with **47Ω** (I ≈ (5−1.35−0.2)/47 ≈ 74mA — within TSAL6400 100mA continuous max)
3. Toggle YAML still active at 1Hz
4. Verification methods (in order of preference):
   - a) Smartphone front camera: TSAL6400 should flash faintly (violet/white glow).
     First validate the camera can see IR: point the original Technibel remote at it.
     If the remote is visible but the TSAL6400 is not → LED problem.
     If neither is visible → camera filters 940nm, skip to electrical verification.
   - b) Electrical verification (primary proof): measure voltage across the 47Ω resistor
     during ON state. I = V_across_47Ω / 47. With a 5.0–5.2V USB rail and TSAL6400
     forward voltage around 1.35–1.6V, expect approximately 3.6–3.9V → ~75–83mA.
     This proves the LED is conducting the correct current.
   - **Do NOT use KY-022 at this phase.** The KY-022/VS1838B is a demodulating receiver
     tuned to 38kHz. A 1Hz toggle (DC illumination) is not a 38kHz-modulated signal.
     The receiver may produce a transient but it is not a reliable proof of emission.
     Optical validation with KY-022 happens in Phase 7 with proper 38kHz carrier.

**Note on resistor rating**: 47Ω at 74mA = 0.26W. Marginal for a ¼W resistor at 500ms ON.
Use a ½W resistor, or move quickly to Phase 7 (modulated pulses, much lower duty cycle).

**Gatekeeper 6**:

| Test | Pass | Fail action |
|---|---|---|
| Smartphone sees TSAL6400 flash (camera pre-validated with remote) | IR LED emits | Swap LED polarity, try another TSAL |
| V across 47Ω ≈ 3.6–4.0V during ON | Current ~75–85mA, LED conducting and below the TSAL6400 100mA continuous rating | Wrong resistor value or 5V supply issue |

---

### Phase 7 — 38kHz carrier: remote_transmitter with NEC test

**Goal**: send a real modulated IR signal and capture it with the KY-022.

This test validates the **hardware IR chain** (GPIO → RMT → transistor → LED → optical path → receiver).
If NEC works, the hardware is validated. The Technibel protocol itself is validated separately in Phase 8.

**Actions**:

1. Remove toggle YAML, add `remote_transmitter` config:
   ```yaml
   remote_transmitter:
     id: ir_tx
     pin: GPIO3
     carrier_duty_percent: 50%
     non_blocking: false    # explicit — default is true in current ESPHome
     rmt_symbols: 96        # C3 has 96 symbols total (2 blocks of 48)
                            # Technibel frame = 99 raw values ≈ 50 RMT symbols
   ```
2. Add a test service:
   ```yaml
   api:
     services:
       - service: test_nec
         then:
           - remote_transmitter.transmit_nec:
               address: 0x1234
               command: 0x5678
   ```
3. Set up KY-022 sniffer on a **second board** (another XIAO, or the old ESP32 DevKit if 3.3V works)
   with the sniffer YAML adapted for the board
4. Place KY-022 facing TSAL6400 at ~5cm
5. Trigger `test_nec` from ESPHome dashboard (Developer Tools → Services)
6. Check sniffer logs: NEC frame must appear with address 0x1234, command 0x5678

   With ESPHome 2026.7, `dump: all` may label this capture `Beo4` and also emit a
   Pronto/raw line instead of an explicit `NEC` line. In that case, decode the 32
   NEC spaces manually: the expected little-endian bytes are `34 12 78 56`, which
   correspond to address `0x1234` and command `0x5678`.

**Logic analyzer verification** (parallel, safe on bench — no mains voltage involved):

- The available analyzer is an 8-channel, 24 MHz USB analyzer labelled `CH1`–`CH8`
  (there is no `CH0`). Connect its `CH1` lead to GPIO3 (XIAO C3).
- Connect the analyzer `GND` lead to XIAO GND. Power the analyzer from its USB cable;
  leave its `PWR` lead disconnected because the XIAO is powered independently.
- Trigger test_nec
- In PulseView, select the 24 MHz analyzer when practical (2 MHz is sufficient for
  this bench check), and verify 38 kHz carrier modulation and correct NEC timing.
- In PulseView: verify 38kHz carrier modulation, correct NEC timing

**Gatekeeper 7**:

| Test | Pass | Fail action |
|---|---|---|
| KY-022 decodes NEC in logs, or raw Pronto timings manually decode to `34 12 78 56` | Hardware IR chain validated | Check carrier_duty_percent, try esp-idf framework |
| Logic analyzer shows 38kHz on GPIO3 | RMT works on C3 | Note exact error, check ESPHome version ≥2024.6, try esp-idf framework, verify no other component uses TX RMT channels |
| Range > 30cm from KY-022 | Sufficient for Piste A at close range | Add 2nd TSAL6400 in parallel (each with own 47Ω). 1m+ range is nice-to-have, not a gate. |
| Compiles without RMT error | Symbol allocation OK | Keep rmt_symbols: 96, check ESPHome version, check for conflicting RMT users |

**Optional**: test with GT1087 Go Tronic module as a secondary data point. However,
the GT1087 has its own unknown characteristics (input polarity, driver stage, LED spec)
that must be verified independently before drawing conclusions. It is NOT a drop-in
replacement for the discrete circuit — treat it as a separate experiment, not a control.

---

### Phase 8 — Technibel protocol: full frame comparison

**Goal**: send a real Technibel frame and compare it with the original remote.

**Actions**:

1. Activate the full YAML with `technibel_ir.h` include and `send_command` service:
   ```yaml
   esphome:
     includes:
       - ./libraries/technibel_ir.h
   ```
   Verify the `includes:` path resolves correctly in the dedicated VM's live ESPHome environment, not just in the repository.

2. Capture two frames with the KY-022 sniffer:
   - a) **Original remote**: COOL, 24°C, FAN AUTO
   - b) **ESP32 C3**: `send_command` with mode=COOL, consigne=24, fan=AUTO, t_amb=25

3. **Decoding procedure** (the sniffer outputs raw/Pronto, NOT hex bytes):
   - a) Capture the raw timing sequence from ESPHome logs
   - b) Strip the header pulse (6500µs mark + 3300µs space)
   - c) Classify each space: > 1500µs → bit 1, < 1500µs → bit 0
   - d) Group into 6 bytes, MSB first per byte
   - e) Display as hex: B0 B1 B2 B3 B4 B5
   - f) **Save both raw captures as validation artifacts** (paste into a file)

4. Compare the 6 bytes

**Expected frame** for COOL 24°C FAN_AUTO power_ON t_amb=25:

```
B0 = 0xD0  (fixed device address)
B1 = 0xAC  (ambient 25°C high nibble + COOL mode nibble)
B2 = 0x28  (temp_hi=0x2 for 24°C, fan_lo=0x8 for AUTO)
B3 = 0x18  (power ON)
B4 = 0x03  (fixed)
B5 = 0x34  (checksum for the captured 24°C frame and t_amb=25:
           reverse(reverse(0x28) + reverse(0x18) + 25 - 25)
           = reverse(0x14 + 0x18) = reverse(0x2C) = 0x34)
```

**Validated reference frame: `D0 AC 28 18 03 34`**

**Comparing with the original remote** — the `t_amb` problem:

The remote uses its own temperature sensor, which won't be exactly 25°C.
A B5 difference must NEVER be accepted without explanation. Procedure:

1. From the remote's captured B5, reverse-compute t_amb:
   ```
   t_amb = (reverse(B5_captured) - reverse(B2) - reverse(B3) + 25) & 0xFF
   ```
2. Verify the result is an integer and physically plausible (15–40°C)
3. Re-generate B5 from this t_amb value — it must match the captured B5 exactly
4. Use this same t_amb in the ESP32's `send_command` and verify B5 matches

If step 2 gives an implausible value or step 3 doesn't match, there is a protocol
error — do not attribute it to "temperature difference".

**Gatekeeper 8**:

| Test | Pass | Fail action |
|---|---|---|
| B0–B4 identical between ESP32 and remote | Protocol encoding correct | Debug encoding (should not happen — code is frozen) |
| B5 from remote reverse-computed to plausible t_amb (15–40°C) | Checksum formula correct | Formula error — re-verify against protocol.md |
| ESP32 B5 matches remote B5 when using same reverse-computed t_amb | End-to-end checksum validated | Bit error — compare raw captures bit by bit |
| ESP32 frame matches reference `D0 AC 28 18 03 34` (with t_amb=25) | Independent verification | Check t_amb value used |
| Timings within ±10% of remote | Acceptable by AC | Timing constants may be adjusted (see note below) |

**Note on `technibel_ir.h` freeze scope**: the frame builder (encoding, checksum) is frozen.
The timing constants (header/bit pulse/space durations) may be adjusted if instrumented
comparison shows they differ from the original remote by more than 10%. This is the only
permitted modification.

---

### Phase 9 — Live test on the AC unit: Piste A validation

**Goal**: the AC unit responds to an IR command from the ESP32.

**Actions**:

1. Position XIAO + TSAL6400 at ~30cm facing the AC receiver window
2. Send: COOL, 24°C, FAN AUTO, t_amb = actual room temperature
3. Observe: AC must beep and change mode
4. Test all 4 modes + OFF systematically:

| # | Command | Expected AC response |
|---|---|---|
| 1 | COOL 24°C FAN_AUTO | AC starts cooling, display shows 24°C |
| 2 | Change to 22°C | Display changes to 22°C |
| 3 | DRY mode | AC switches to dehumidification |
| 4 | FAN mode | AC switches to fan only |
| 5 | AUTO mode | AC switches to auto |
| 6 | OFF | AC turns off (beep, display off) |
| 7 | COOL 24°C again | AC turns back on |

5. **Frame repeat test**:
   - Capture the original remote with the sniffer: does it send 1 frame or 2-3 per button press?
   - If remote sends multiple frames: add repeat in the YAML service (send twice with 40ms gap)
   - If remote sends once: current implementation is correct

**Gatekeeper 9**:

| Test | Pass | Fail action |
|---|---|---|
| AC beeps on first command | **Signal received** | Move closer (5cm), add 2nd LED, check angle |
| All 4 modes + OFF work | **PISTE A VALIDATED** | Debug failing mode individually |
| ON/OFF works | Power control OK | Check B3 encoding (0x18/0x08) |
| Temperature change works | Temp encoding OK | Check B2 hi nibble encoding |
| Repeat 10× without failure | Reliable | Check timing drift, power stability, frame repeats |

---

### Phase 10 — Preserve Piste A as reference

**Goal**: keep the validated Piste A hardware intact as fallback/reference.

**Actions**:
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

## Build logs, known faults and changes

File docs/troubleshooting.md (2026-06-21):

# Dépannage circuit IR / IR Circuit Troubleshooting

**[🇫🇷 Français](#-français)** · **[🇬🇧 English](#-english)**

---

## 🇫🇷 Français

### Symptôme : la LED IR n'émet rien (caméra ne voit aucun flash)

> Note : le test caméra smartphone n'est **pas fiable** pour les LED IR à 940nm (TSAL6400).
> La plupart des téléphones modernes ont un filtre qui bloque cette longueur d'onde.
> Vérifier d'abord avec une télécommande TV : si la caméra ne voit pas non plus la télécommande, elle est inutilisable pour ce test.

---

### Étape 1 — Vérifier le transistor (hors circuit, multimètre mode diode ►|)

Retirer le transistor de la breadboard. Face plate vers soi, pattes vers le bas :

| Sonde rouge | Sonde noire | Valeur attendue |
|---|---|---|
| Base (milieu) | Emitter (gauche) | ~600–700 mV |
| Base (milieu) | Collector (droite) | ~600–700 mV |
| Toute autre combinaison | | OL (circuit ouvert) |

- Valeurs ~650 mV dans les deux premiers cas → **transistor OK**
- OL dans les deux premiers cas → **transistor mort**, le remplacer

---

### Étape 2 — Vérifier la LED IR (hors circuit, multimètre mode diode ►|)

| Sonde rouge | Sonde noire | Valeur attendue |
|---|---|---|
| Anode (longue patte) | Cathode (courte patte) | ~1.0–1.4 V |
| Cathode | Anode | OL |

- ~1.1–1.4 V dans le premier sens → **LED OK**
- OL dans les deux sens → **LED morte**, la remplacer

---

### Étape 3 — Vérifier le câblage (multimètre mode continuité, bip)

Tester chaque maillon de la chaîne séparément.

> ⚠️ Une résistance (47Ω ou 470Ω) ne bipe **pas** en mode continuité — c'est normal.
> Tester chaque côté de la résistance séparément.

| De | Vers | Attendu |
|---|---|---|
| Fil GND | Patte Emitter (gauche) du transistor | bip |
| Fil GPIO4 | Patte d'entrée de la résistance 470Ω | bip |
| Patte de sortie de la résistance 470Ω | Patte Base (milieu) du transistor | bip |
| Patte Collector (droite) du transistor | Cathode LED (courte patte) | bip |
| Fil 5V | Patte d'entrée de la résistance 47Ω | bip |
| Patte de sortie de la résistance 47Ω | Anode LED (longue patte) | bip |

Un bip manquant = connexion coupée à cet endroit (patte pas dans la bonne rangée breadboard, ou fil mal inséré).

---

### Étape 4 — Vérifier les tensions en circuit (multimètre DC, fil noir sur GND)

Alimenter l'ESP32 et envoyer une commande IR depuis Home Assistant pendant la mesure.

| Point de mesure | Valeur attendue | Si anormal |
|---|---|---|
| Fil 5V (avant résistance 47Ω) | ~5 V | Mauvaise broche ESP32 (Vin vs 3V3) |
| Base du transistor (patte milieu) | ~0.3–0.7 V (signal pulsé) | GPIO4 ne pilote pas le transistor |
| Collector du transistor (patte droite) | chute à ~0.2 V pendant IR | Transistor ne conduit pas |
| Anode LED (longue patte) | ~1.5 V pendant IR, ~5 V au repos | Circuit LED ouvert |

---

### Rappel brochage 2N2222A TO-92

```
Face plate avec inscription vers soi, pattes vers le bas :

┌──────────┐
│ 2N2222A  │
└──────────┘
  │    │    │
  E    B    C
(GND)(sig)(LED cathode)
```

---

## 🇬🇧 English

### Symptom: IR LED emits nothing (camera sees no flash)

> Note: smartphone camera test is **not reliable** for 940nm IR LEDs (TSAL6400).
> Most modern phones have an IR cut filter at this wavelength.
> First test with a TV remote: if the camera can't see the remote either, it cannot be used for this test.

---

### Step 1 — Check the transistor (out of circuit, multimeter diode mode ►|)

Remove transistor from breadboard. Flat face toward you, pins pointing down:

| Red probe | Black probe | Expected |
|---|---|---|
| Base (middle) | Emitter (left) | ~600–700 mV |
| Base (middle) | Collector (right) | ~600–700 mV |
| Any other combination | | OL (open circuit) |

- ~650 mV in first two cases → **transistor OK**
- OL in first two cases → **transistor dead**, replace it

---

### Step 2 — Check the IR LED (out of circuit, multimeter diode mode ►|)

| Red probe | Black probe | Expected |
|---|---|---|
| Anode (long leg) | Cathode (short leg) | ~1.0–1.4 V |
| Cathode | Anode | OL |

- ~1.1–1.4 V in forward direction → **LED OK**
- OL in both directions → **LED dead**, replace it

---

### Step 3 — Check wiring (multimeter continuity mode, beep)

Test each link in the chain separately.

> ⚠️ A resistor (47Ω or 470Ω) will **not** beep in continuity mode — this is normal.
> Test each side of the resistor separately.

| From | To | Expected |
|---|---|---|
| GND wire | Transistor Emitter (left pin) | beep |
| GPIO4 wire | Input leg of 470Ω resistor | beep |
| Output leg of 470Ω resistor | Transistor Base (middle pin) | beep |
| Transistor Collector (right pin) | LED Cathode (short leg) | beep |
| 5V wire | Input leg of 47Ω resistor | beep |
| Output leg of 47Ω resistor | LED Anode (long leg) | beep |

Missing beep = broken connection at that point (leg not in the same breadboard row, or wire not fully inserted).

---

### Step 4 — Check voltages in circuit (DC mode, black probe on GND)

Power the ESP32 and send an IR command from Home Assistant during measurement.

| Measurement point | Expected value | If abnormal |
|---|---|---|
| 5V wire (before 47Ω resistor) | ~5 V | Wrong ESP32 pin (Vin vs 3V3) |
| Transistor Base (middle pin) | ~0.3–0.7 V (pulsed signal) | GPIO4 not driving transistor |
| Transistor Collector (right pin) | drops to ~0.2 V during IR | Transistor not conducting |
| LED Anode (long leg) | ~1.5 V during IR, ~5 V idle | LED circuit open |

---

### 2N2222A TO-92 pinout reminder

```
Flat face with text toward you, pins pointing down:

┌──────────┐
│ 2N2222A  │
└──────────┘
  │    │    │
  E    B    C
(GND)(sig)(LED cathode)
```

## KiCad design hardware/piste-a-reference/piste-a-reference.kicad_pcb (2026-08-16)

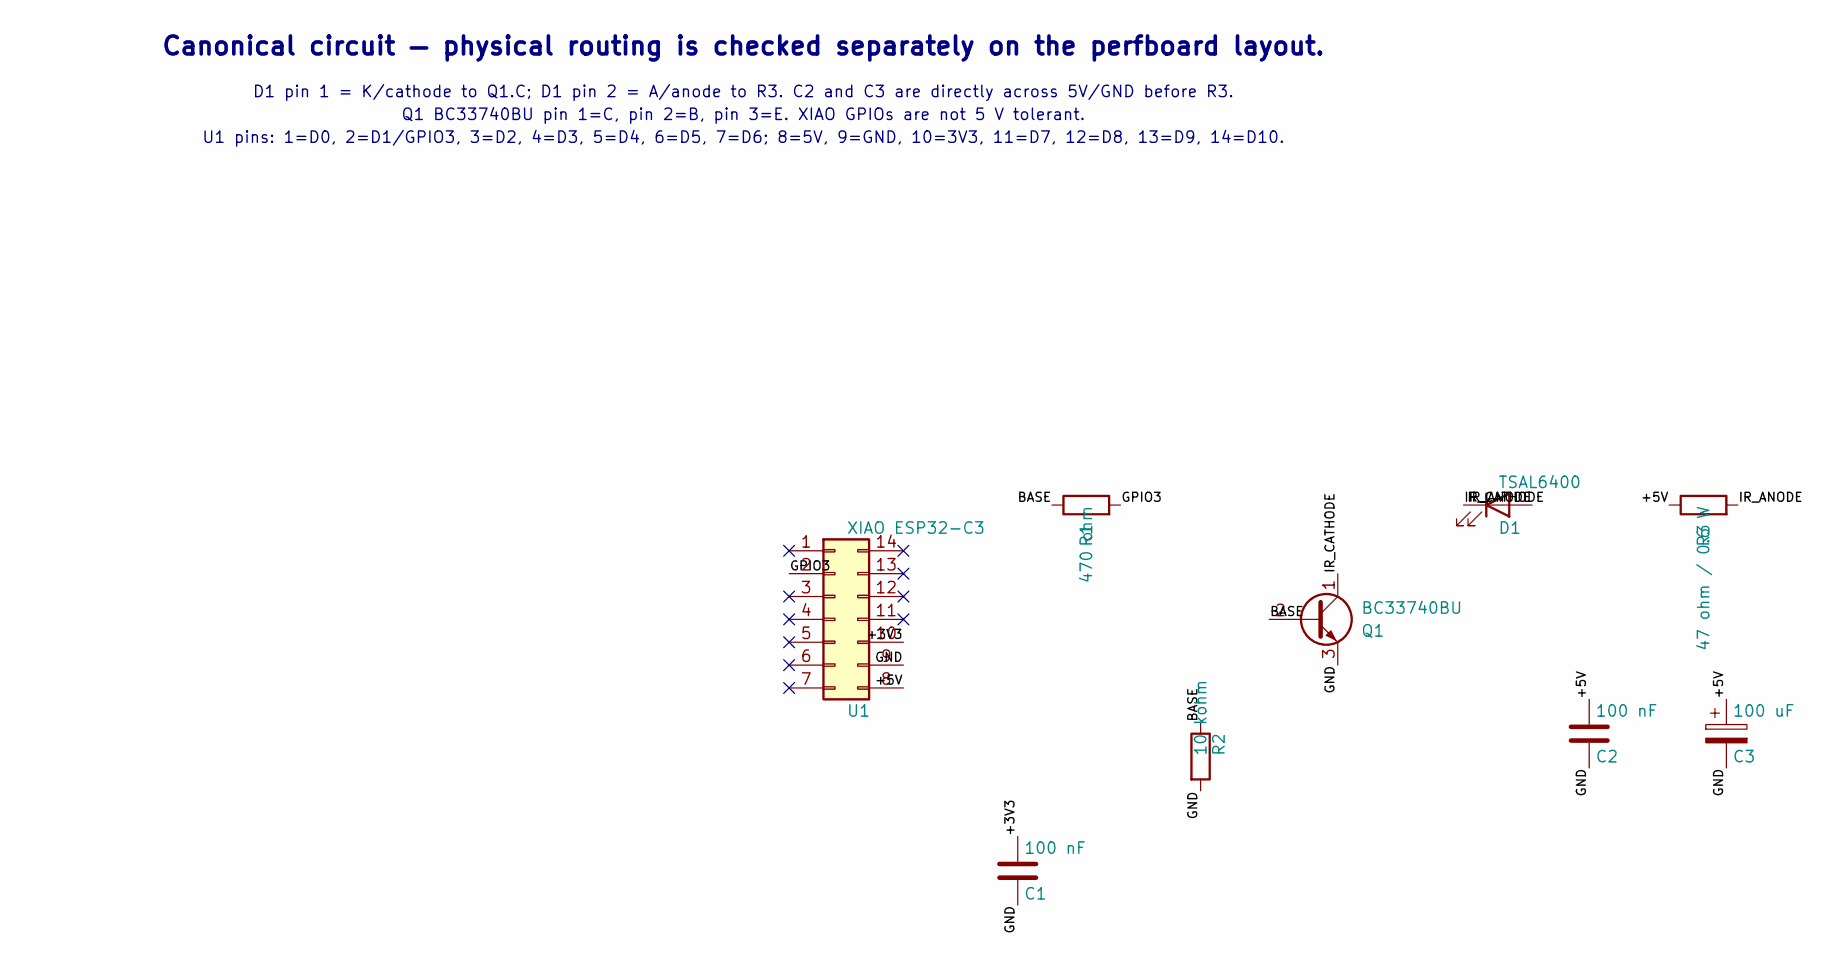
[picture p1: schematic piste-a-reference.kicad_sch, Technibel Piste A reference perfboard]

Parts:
C1, C2: 100 nF
C3: 100 uF
D1: TSAL6400
Q1: BC33740BU
R1: 470 ohm
R2: 10 kohm
R3: 47 ohm / 0.6 W
U1: XIAO ESP32-C3

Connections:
+3V3: C1.1, U1.10
+5V: C2.1, C3.1, R3.1, U1.8
BASE: Q1.2 (B), R1.1, R2.1
GND: C1.2, C2.2, C3.2, Q1.3 (E), R2.2, U1.9
GPIO3: R1.2, U1.2
IR_ANODE: D1.2 (A), R3.2
IR_CATHODE: D1.1 (K), Q1.1 (C)

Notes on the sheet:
Canonical circuit — physical routing is checked separately on the perfboard layout.
D1 pin 1 = K/cathode to Q1.C; D1 pin 2 = A/anode to R3. C2 and C3 are directly across 5V/GND before R3.
Q1 BC33740BU pin 1=C, pin 2=B, pin 3=E. XIAO GPIOs are not 5 V tolerant.
U1 pins: 1=D0, 2=D1/GPIO3, 3=D2, 4=D3, 5=D4, 6=D5, 7=D6; 8=5V, 9=GND, 10=3V3, 11=D7, 12=D8, 13=D9, 14=D10.

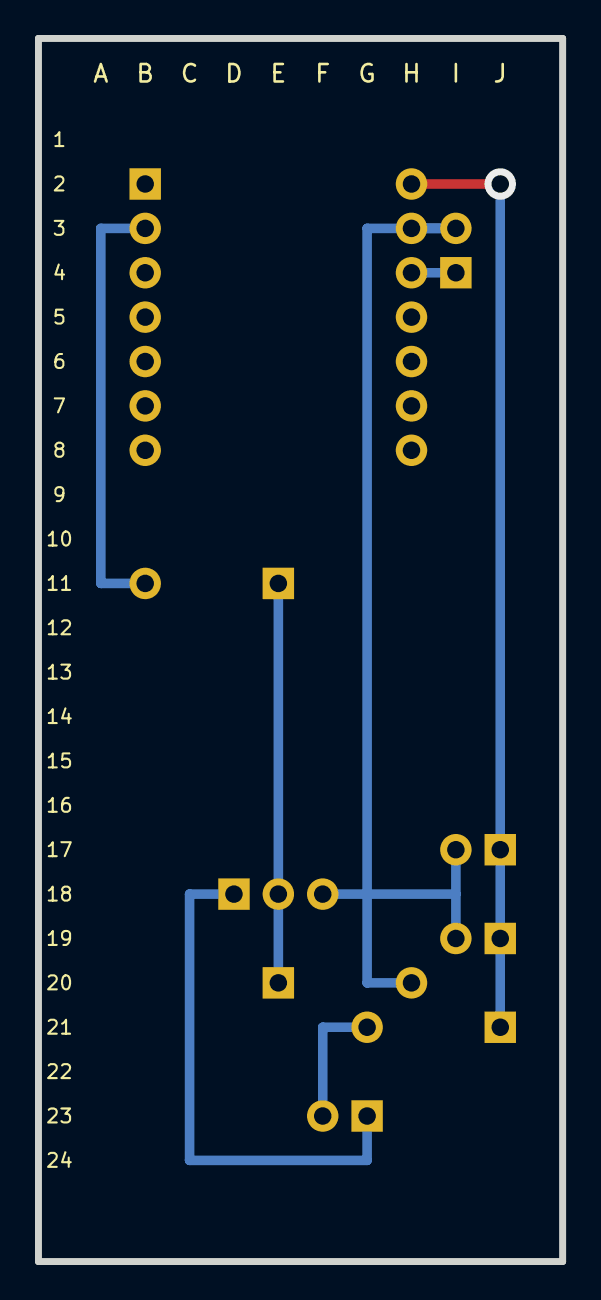
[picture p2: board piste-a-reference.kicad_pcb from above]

Board: 2 copper layers, 30.0 x 70.0 mm, 9 parts (0 on the bottom side), 7 nets.

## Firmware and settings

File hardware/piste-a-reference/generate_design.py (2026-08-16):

#!/usr/bin/env python3
"""Generate the checked KiCad schematic and perfboard layout for Piste A.

Run with a Python environment containing ``kicad-sch-api``. KiCad itself is
used afterwards for ERC, DRC, and printable exports.
"""

from pathlib import Path

import kicad_sch_api as ksa


ROOT = Path(__file__).resolve().parent
SCH = ROOT / "piste-a-reference.kicad_sch"
PCB = ROOT / "piste-a-reference.kicad_pcb"
WIRE_TABLE = ROOT / "wiring-table.md"

PITCH = 2.54
BOARD_X = 100.0
BOARD_Y = 50.0
BOARD_W = 30.0
BOARD_H = 70.0
GRID_X = BOARD_X + (BOARD_W - 9 * PITCH) / 2
GRID_Y = BOARD_Y + (BOARD_H - 23 * PITCH) / 2

NETS = {
    "+3V3": 1,
    "+5V": 2,
    "BASE": 3,
    "GND": 4,
    "GPIO3": 5,
    "IR_ANODE": 6,
    "IR_CATHODE": 7,
}


def xy(coord: str) -> tuple[float, float]:
    """Convert a perfboard coordinate such as H8 to KiCad millimetres."""
    col = ord(coord[0].upper()) - ord("A")
    row = int(coord[1:]) - 1
    if not 0 <= col < 10 or not 0 <= row < 24:
        raise ValueError(f"Invalid perfboard coordinate: {coord}")
    return GRID_X + col * PITCH, GRID_Y + row * PITCH


def fmt(value: float) -> str:
    return f"{value:.3f}".rstrip("0").rstrip(".")


def fp_text(kind: str, text: str, x: float, y: float, layer: str = "F.Fab", size: float = 0.9,
            hidden: bool = False) -> str:
    hidden_expr = " (hide yes)" if hidden else ""
    return (
        f'    (property "{kind}" "{text}" (at {fmt(x)} {fmt(y)}) (layer "{layer}") '
        f'(effects (font (size {size} {size}) (thickness 0.15))){hidden_expr})\n'
    )


def pad(number: str, coord: str, net: str | None, shape: str = "circle") -> str:
    x, y = xy(coord)
    net_expr = "" if net is None else f' (net {NETS[net]} "{net}")'
    return (
        f'    (pad "{number}" thru_hole {shape} (at {fmt(x)} {fmt(y)}) '
        f'(size 1.8 1.8) (drill 1) (layers "*.Cu" "*.Mask"){net_expr})\n'
    )


def footprint(reference: str, value: str, pads: list[tuple[str, str, str | None]],
              outline: tuple[str, str] | None = None, notes: list[str] | None = None) -> str:
    xs = [xy(coord)[0] for _, coord, _ in pads]
    ys = [xy(coord)[1] for _, coord, _ in pads]
    cx = sum(xs) / len(xs)
    cy = sum(ys) / len(ys)
    result = [f'  (footprint "{reference}" (layer "F.Cu")\n']
    result.append(fp_text("Reference", reference, cx, min(ys) - 1.8))
    result.append(fp_text("Value", value, cx, max(ys) + 1.8, "F.Fab", 0.8, hidden=True))
    if outline:
        x1, y1 = xy(outline[0])
        x2, y2 = xy(outline[1])
        result.append(
            f'    (fp_rect (start {fmt(x1 - 1)} {fmt(y1 - 1)}) '
            f'(end {fmt(x2 + 1)} {fmt(y2 + 1)}) '
            '(stroke (width 0.3) (type default)) (fill none) (layer "F.Fab"))\n'
        )
    for number, coord, net in pads:
        result.append(pad(number, coord, net, "rect" if number == "1" else "circle"))
    if notes:
        for index, note in enumerate(notes):
            result.append(
                f'    (fp_text user "{note}" (at {fmt(cx)} {fmt(max(ys) + 3.3 + index * 1.4)}) '
                '(layer "F.Fab") (effects (font (size 0.8 0.8) (thickness 0.12))))\n'
            )
    result.append("  )\n")
    return "".join(result)


WIRES = [
    ("W01", "GPIO3", "YELLOW", "B3", "A3"),
    ("W02", "GPIO3", "YELLOW", "A3", "A11"),
    ("W03", "GPIO3", "YELLOW", "A11", "B11"),
    ("W04", "BASE", "YELLOW", "E11", "E18"),
    ("W05", "BASE", "YELLOW", "E18", "E20"),
    ("W06", "+3V3", "YELLOW", "H4", "I4"),
    ("W07", "GND", "BLACK", "H3", "I3"),
    ("W08", "GND", "BLACK", "I3", "G3"),
    ("W09", "GND", "BLACK", "F18", "G18"),
    ("W10", "GND", "BLACK", "H20", "G20"),
    ("W11", "+5V", "RED", "H2", "J2"),
    ("W12", "+5V", "RED", "J2", "J21"),
    ("W13", "IR_ANODE", "YELLOW", "F21", "F23"),
    ("W14", "IR_CATHODE", "YELLOW", "D18", "C18"),
    ("W15", "IR_CATHODE", "YELLOW", "C18", "C24"),
    ("W16", "IR_CATHODE", "YELLOW", "C24", "G24"),
    ("W17", "IR_CATHODE", "YELLOW", "G24", "G23"),
    ("W18", "GND", "BLACK", "G3", "G18"),
    ("W19", "GND", "BLACK", "G18", "I18"),
    ("W20", "GND", "BLACK", "G18", "G20"),
    ("W21", "GND", "BLACK", "I17", "I18"),
    ("W22", "GND", "BLACK", "I18", "I19"),
    ("W23", "IR_ANODE", "YELLOW", "G21", "F21"),
]

TOP_SIDE_JUMPERS = {"W11"}


def build_pcb() -> None:
    lines = [
        '(kicad_pcb (version 20241229) (generator "pcbnew") (generator_version "9.0")\n',
        '  (general (thickness 1.6))\n',
        '  (paper "A4")\n',
        '  (layers\n',
        '    (0 "F.Cu" signal)\n',
        '    (2 "B.Cu" signal)\n',
        '    (5 "F.SilkS" user "F.Silkscreen")\n',
        '    (7 "B.SilkS" user "B.Silkscreen")\n',
        '    (1 "F.Mask" user)\n',
        '    (3 "B.Mask" user)\n',
        '    (17 "Dwgs.User" user "User.Drawings")\n',
        '    (25 "Edge.Cuts" user)\n',
        '    (31 "F.CrtYd" user "F.Courtyard")\n',
        '    (29 "B.CrtYd" user "B.Courtyard")\n',
        '    (35 "F.Fab" user)\n',
        '    (33 "B.Fab" user)\n',
        '  )\n',
        '  (setup (pad_to_mask_clearance 0))\n',
        '  (net 0 "")\n',
    ]
    for name, number in sorted(NETS.items(), key=lambda item: item[1]):
        lines.append(f'  (net {number} "{name}")\n')

    # XIAO: component-side view, USB connector toward row 1.
    u1_pads = [
        ("1", "B2", None), ("2", "B3", "GPIO3"), ("3", "B4", None),
        ("4", "B5", None), ("5", "B6", None), ("6", "B7", None), ("7", "B8", None),
        ("8", "H2", "+5V"), ("9", "H3", "GND"), ("10", "H4", "+3V3"),
        ("14", "H5", None), ("13", "H6", None), ("12", "H7", None), ("11", "H8", None),
    ]
    lines.append(footprint(
        "U1", "XIAO ESP32-C3", u1_pads, ("A1", "I9"),
        None,
    ))
    lines.append(footprint("R1", "470 ohm", [("2", "B11", "GPIO3"), ("1", "E11", "BASE")], ("B11", "E11")))
    lines.append(footprint("Q1", "BC33740BU C-B-E", [("1", "D18", "IR_CATHODE"), ("2", "E18", "BASE"), ("3", "F18", "GND")], ("D18", "F18")))
    lines.append(footprint("R2", "10 kohm", [("1", "E20", "BASE"), ("2", "H20", "GND")], ("E20", "H20")))
    lines.append(footprint("C1", "100 nF", [("2", "I3", "GND"), ("1", "I4", "+3V3")], ("I3", "I4")))
    lines.append(footprint("C2", "100 nF", [("2", "I17", "GND"), ("1", "J17", "+5V")], ("I17", "J17")))
    lines.append(footprint("C3", "100 uF", [("2", "I19", "GND"), ("1", "J19", "+5V")], ("I19", "J19")))
    lines.append(footprint("R3", "47 ohm / 0.6 W", [("1", "J21", "+5V"), ("2", "G21", "IR_ANODE")], ("G21", "J21")))
    lines.append(footprint("D1", "TSAL6400", [("2", "F23", "IR_ANODE"), ("1", "G23", "IR_CATHODE")], ("F23", "G23")))

    # Board edge and coordinate grid.
    x1, y1 = BOARD_X, BOARD_Y
    x2, y2 = BOARD_X + BOARD_W, BOARD_Y + BOARD_H
    for start, end in [((x1, y1), (x2, y1)), ((x2, y1), (x2, y2)), ((x2, y2), (x1, y2)), ((x1, y2), (x1, y1))]:
        lines.append(
            f'  (gr_line (start {fmt(start[0])} {fmt(start[1])}) (end {fmt(end[0])} {fmt(end[1])}) '
            '(stroke (width 0.4) (type default)) (layer "Edge.Cuts"))\n'
        )
    for col in "ABCDEFGHIJ":
        x, _ = xy(f"{col}1")
        lines.append(f'  (gr_text "{col}" (at {fmt(x)} {fmt(BOARD_Y + 2)}) (layer "F.SilkS") (effects (font (size 1 1) (thickness 0.15))))\n')
    for row in range(1, 25):
        _, y = xy(f"A{row}")
        lines.append(f'  (gr_text "{row}" (at {fmt(BOARD_X + 1.2)} {fmt(y)}) (layer "F.SilkS") (effects (font (size 0.8 0.8) (thickness 0.12))))\n')
        for col in "ABCDEFGHIJ":
            x, _ = xy(f"{col}{row}")
            lines.append(
                f'  (gr_circle (center {fmt(x)} {fmt(y)}) (end {fmt(x + 0.65)} {fmt(y)}) '
                '(stroke (width 0.12) (type default)) (fill none) (layer "Dwgs.User"))\n'
            )

    # Insulated point-to-point wires are represented as B.Cu for deterministic DRC.
    for wire_id, net, _color, start, end in WIRES:
        sx, sy = xy(start)
        ex, ey = xy(end)
        layer = "F.Cu" if wire_id in TOP_SIDE_JUMPERS else "B.Cu"
        lines.append(
            f'  (segment (start {fmt(sx)} {fmt(sy)}) (end {fmt(ex)} {fmt(ey)}) '
            f'(width 0.55) (layer "{layer}") (net {NETS[net]}))\n'
        )
    # J2 is the soldered handoff between the component-side 5 V jumper W11
    # and the solder-side 5 V rail W12.
    j8x, j8y = xy("J2")
    lines.append(
        f'  (via (at {fmt(j8x)} {fmt(j8y)}) (size 1.8) (drill 1) '
        f'(layers "F.Cu" "B.Cu") (net {NETS["+5V"]}))\n'
    )
    lines.append(")\n")
    PCB.write_text("".join(lines), encoding="utf-8")


def build_wire_table() -> None:
    rows = [
        "# Piste A perfboard wiring table\n\n",
        "Coordinate convention: component-side view, USB-C toward row 1. The solder-side drawing is mirrored by KiCad.\n\n",
        "| Wire | Net | Color | Side | From | To | Straight length |\n",
        "|---|---|---|---|---|---|---:|\n",
    ]
    for wire_id, net, color, start, end in WIRES:
        sx, sy = xy(start)
        ex, ey = xy(end)
        length = abs(ex - sx) + abs(ey - sy)
        side = "component-side jumper" if wire_id in TOP_SIDE_JUMPERS else "solder side"
        rows.append(f"| {wire_id} | `{net}` | {color} | {side} | `{start}` | `{end}` | {length:.1f} mm |\n")
    rows.extend([
        "\n## Component coordinates\n\n",
        "| Ref | Value | Pin coordinates |\n",
        "|---|---|---|\n",
        "| U1 | XIAO ESP32-C3, 2x7 sockets | pin 2/D1/GPIO3=`B3`; pin 8/5V=`H2`; pin 9/GND=`H3`; pin 10/3V3=`H4`; all 14 pins represented |\n",
        "| R1 | 470 ohm | 2/GPIO3=`B11`; 1/BASE=`E11` |\n",
        "| Q1 | BC33740BU | 1/C=`D18`; 2/B=`E18`; 3/E=`F18` |\n",
        "| R2 | 10 kohm | 1/BASE=`E20`; 2/GND=`H20` |\n",
        "| C1 | 100 nF | 2/GND=`I3`; 1/3V3=`I4` |\n",
        "| C2 | 100 nF | 2/GND=`I17`; 1/5V=`J17` |\n",
        "| C3 | 100 uF | 2/GND=`I19`; 1/+5V=`J19` |\n",
        "| R3 | 47 ohm / 0.6 W | 1/5V=`J21`; 2/IR_ANODE=`G21` |\n",
        "| D1 | fresh TSAL6400 | 2/A=`F23`; 1/K=`G23` |\n",
    ])
    WIRE_TABLE.write_text("".join(rows), encoding="utf-8")


def build_schematic() -> None:
    sch = ksa.create_schematic("Technibel Piste A reference perfboard")
    sch.set_paper_size("A4")
    sch.set_title_block(
        title="Technibel Piste A reference perfboard",
        date="2026-08-16",
        rev="1",
        company="esphome-technibel-scdf32",
        comments={
            1: "BC33740BU: C-B-E with flat face toward viewer",
            2: "Fresh TSAL6400: verify A/K before soldering",
        },
    )

    add = sch.components.add
    add("Connector_Generic:Conn_02x07_Counter_Clockwise", "U1", "XIAO ESP32-C3", (35.56, 88.9))
    add("Device:R", "R1", "470 ohm", (63.5, 76.2), rotation=90)
    add("Transistor_BJT:Q_NPN_CBE", "Q1", "BC33740BU", (88.9, 88.9))
    add("Device:R", "R2", "10 kohm", (76.2, 104.14))
    add("Device:LED", "D1", "TSAL6400", (109.22, 76.2))
    add("Device:R", "R3", "47 ohm / 0.6 W", (132.08, 76.2), rotation=90)
    add("Device:C", "C2", "100 nF", (119.38, 101.6))
    add("Device:C_Polarized", "C3", "100 uF", (134.62, 101.6))
    add("Device:C", "C1", "100 nF", (55.88, 116.84))

    nets = {
        "GPIO3": [("U1", "2"), ("R1", "1")],
        "BASE": [("R1", "2"), ("Q1", "2"), ("R2", "1")],
        "GND": [
            ("U1", "9"),
            ("Q1", "3"),
            ("R2", "2"),
            ("C1", "2"),
            ("C2", "2"),
            ("C3", "2"),
        ],
        "IR_CATHODE": [("Q1", "1"), ("D1", "1")],
        "IR_ANODE": [("D1", "2"), ("R3", "1")],
        "+5V": [("U1", "8"), ("R3", "2"), ("C2", "1"), ("C3", "1")],
        "+3V3": [("U1", "10"), ("C1", "1")],
    }
    for net_name, pins in nets.items():
        for ref, pin in pins:
            sch.add_label(net_name, pin=(ref, pin), size=1.0)
    for pin in ("1", "3", "4", "5", "6", "7", "11", "12", "13", "14"):
        position = sch.get_component_pin_position("U1", pin)
        if position is None:
            raise RuntimeError(f"Could not locate unused U1 pin {pin}")
        sch.no_connects.add(position)

    sch.add_text(
        "Canonical circuit — physical routing is checked separately on the perfboard layout.",
        (25.4, 25.4),
        size=2.0,
        bold=True,
    )
    sch.add_text(
        "D1 pin 1 = K/cathode to Q1.C; D1 pin 2 = A/anode to R3. "
        "C2 and C3 are directly across 5V/GND before R3.",
        (25.4, 30.48),
        size=1.27,
    )
    sch.add_text(
        "Q1 BC33740BU pin 1=C, pin 2=B, pin 3=E. XIAO GPIOs are not 5 V tolerant.",
        (25.4, 33.02),
        size=1.27,
    )
    sch.add_text(
        "U1 pins: 1=D0, 2=D1/GPIO3, 3=D2, 4=D3, 5=D4, 6=D5, 7=D6; "
        "8=5V, 9=GND, 10=3V3, 11=D7, 12=D8, 13=D9, 14=D10.",
        (25.4, 35.56),
        size=1.27,
    )
    sch.save(SCH)


if __name__ == "__main__":
    build_schematic()
    build_pcb()
    build_wire_table()

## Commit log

2026-05-28 Add ESPHome and Home Assistant source files
    - esphome/libraries/technibel_ir.h: C++ IR frame builder (48-bit protocol)
    - esphome/ir-technibel-clim.yaml: IR transmitter ESPHome config
    - esphome/ir-clim-sniffer.yaml: IR receiver config for protocol capture
    - homeassistant/climate-technibel-ha.yaml: MQTT climate package for HA
2026-05-28 Add docs/protocol.md: full bilingual IR protocol documentation
    Complete reverse-engineered protocol spec: frame structure, mode/temperature/
    fan encoding, checksum formula (includes ambient temp), OFF frame, timing.
2026-05-28 Add docs/bom.md and docs/wiring.md: bilingual hardware and wiring guide
2026-06-20 docs: replace PCB0100 module with discrete TSAL6400 + 2N2222 circuit
    The PCB0100 IR emitter module failed in production (indicator LED worked
    but IR LED did not emit). Replaced with a discrete circuit: TSAL6400
    940nm IR LED driven by a 2N2222 NPN transistor (47Ω LED resistor,
    470Ω base resistor). Also documents the multi-LED parallel option for
    wider coverage angle.
2026-06-21 docs: add troubleshooting guide and control strategies, fix wiring for 3V3
    - Add docs/troubleshooting.md: step-by-step multimeter diagnostic protocol
    (transistor/LED diode test, continuity check, in-circuit voltage measurements)
    - Add docs/control-strategies.md: three options for controlling the AC unit
    (IR with LED near receiver, direct TSOP injection, internal PCB bus)
    - Fix docs/wiring.md: Vin pin does not expose USB 5V on many ESP32 boards,
    switch to 3V3 + 22Ω resistor (target ~80mA peak)
    - Update docs/bom.md: note TSAL6400 narrow angle limitation and 3V3/5V resistor variants
    Claude-Session: https://claude.ai/code/session_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
2026-06-21 docs: detail B1b TSOP injection with confirmed ESPHome config
    - Document that TSOP has no electrical input pin — only Signal (output) is
    accessible, making it the sole practical injection point
    - Add 1N4148 diode wiring to prevent conflicts between ESP32 and original remote
    - Confirm firmware change: carrier_duty_percent: 100 + inverted: true on
    remote_transmitter — official ESPHome feature used for 433MHz RF, no carrier
    - technibel_ir.h requires zero changes for B1b
    Claude-Session: https://claude.ai/code/session_014S8WwAvvLzDRqrQzqpUCi9
2026-06-21 docs: add power supply prerequisite section to control strategies
    The internal AC power supply (5V or 12V rail) is the key entry point —
    if tappable, enables a fully integrated install with no external outlet.
    Document the investigation steps and fallback options (buck module or Piste A).
    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
2026-08-15 docs: clarify XIAO USB VBUS power pin
2026-08-15 docs: align TSAL6400 current gate with datasheet
2026-08-15 docs: correct logic analyzer channel wiring
2026-08-15 fix: align Technibel frame encoding with remote captures
2026-08-15 fix: encode ambient temperature in Technibel B1
2026-08-15 docs: log FAN 1 capture pair
2026-08-15 docs: log FAN 2 capture sequence
2026-08-15 docs: log FAN 3 capture
2026-08-15 docs: log FAN 4 capture
2026-08-15 docs: log FAN 5 capture
2026-08-15 docs: log FAN 6 capture pair
2026-08-15 docs: log automatic fan capture
2026-08-15 docs: decode automatic fan frame
2026-08-15 docs: decode complete Technibel fan protocol
2026-08-15 feat: add native seven-speed fan control
2026-08-15 fix: ignore unavailable climate temperature
2026-08-15 docs: correct FAN implementation status
2026-08-15 docs: list all native fan levels
2026-08-16 docs: add corrected Piste A PCB wiring layout
2026-08-16 docs: replace Piste A layout with checked KiCad design
    [piste-a-reference.kicad_pcb, piste-a-reference.kicad_sch]
2026-08-16 fix: correct XIAO top-view pin orientation
    [piste-a-reference.kicad_pcb, piste-a-reference.kicad_sch]
2026-08-16 fix: match Piste A component lead spacing
    [piste-a-reference.kicad_pcb, piste-a-reference.kicad_sch]
2026-10-13 ci: validate tracked YAML syntax without device access (#2)

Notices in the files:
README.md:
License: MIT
